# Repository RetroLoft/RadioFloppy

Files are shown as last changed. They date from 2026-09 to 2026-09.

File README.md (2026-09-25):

# RadioFloppy

WiFi-floppy-emulator voor de Atari ST op basis van een ESP32-S3 (Otronic DevKitC-clone,
16 MB flash, 8 MB PSRAM). Framework: ESP-IDF v5.5.5 (C).

## Hardwaretests

`main/main.c` kiest welke test draait (roep de gewenste functie uit `main/tests.h` aan):

| Test | Bestand | Wat |
| ---- | --- | --- |
| `floppy_emu_run()` (actief) | `main/floppy_app.c`, `ext_flash.c`, `image_store.c`, `drive_emu.c`, `flux_stream.c`, `mfm_track.c`, `disk_image.c` | **Read-only** floppy-emulatie als drive B: (`EMU_SELECT_LINE`). De image komt uit de imagebibliotheek op de externe SPI-flash U2 (S25FL128L, blokgebaseerd, zie `docs/FLASH_LAYOUT.md`) of uit een tijdelijke PSRAM-upload. Alle 168 sporen worden bij het opstarten naar MFM gecodeerd in PSRAM (FlashFloppy-layout voor .ST: geen IAM, GAP4a 80, GAP2 22, GAP3 84). RMT+DMA speelt de fluxstroom op GPIO41 (0,8 us pulsen, 10 MHz), een tweede RMT-kanaal de INDEX-puls op GPIO1 (3 ms per 200 ms, synchroon gestart). WPROT actief zodra geselecteerd; schrijven is uitgeschakeld. |
| `led_test_run()` | `main/led_test.c` | Laat een RGB-LED op GPIO38 blauw en op GPIO48 rood knipperen (om de on-board LED te vinden; op dit board: GPIO48). |
| (oud) `legacy/input_monitor.c` | niet gebouwd | Selectiebewuste monitor met TRACK0 uit de vorige fase, ter referentie. |
| `loopback_test_run()` | `main/loopback_test.c` | Zoekt continu welke Shugart-uitgang (ULN2003A) via een jumper op J1 met welke ingang (SN74LVC245A) verbonden is. |
| `button_test_run()` | `main/button_test.c` | Knoppen: GPIO19 = links (SW_NEXT), GPIO8 = rechts (SW_PREV); piept 0,5 s bij opstarten. |

**Loopbacktest:** de Shugart-lijnen hebben op de PCB geen pull-ups. Plaats op de jumper een
pull-up van 4,7–10 kΩ naar +3V3 (bijv. J3 pin 3, displayconnector), anders komt de lijn na het
vrijgeven van de uitgang niet betrouwbaar HIGH en wordt er niets gemeld.

**Webinterface:** `http://<ip>/` — Current Floppy, uploaden en *My floppy images* (laden, volgorde, vervangen, verwijderen, opslag in %) vanuit de browser
(`web/index.html`, in de firmware ingebouwd); tandwiel rechtsboven = instellingen (hostnaam,
firmware). **Knoppen:** links = vorige disk, rechts = volgende; beide 3 s = hostnaam en IP op het
display; beide 10 s = WiFi-setupmodus.

**WiFi-setupmodus:** zonder ingesteld netwerk (of na 10 s beide knoppen) opent RadioFloppy een
eigen WiFi-netwerk met één setup-pagina (netwerk, beveiliging, wachtwoord). De diskemulatie is dan
uit; het display toont netwerknaam, sleutel en adres. Zie `docs/API.md` → *WiFi setup mode*.

**WiFi en HTTP API:** `docs/API.md` — images uploaden (tijdelijk naar PSRAM of in de imagebibliotheek, tot
1,5 MiB), images activeren, ordenen, vervangen en verwijderen via `/api/v1/`. Hostnaam en WiFi-netwerk staan op de
externe flash (instellingen, setupmodus); `idf.py menuconfig` → *RadioFloppy* geeft alleen de
standaardwaarden en het optionele API-token, en staat alleen in `sdkconfig` (git-ignored). Standaard is de
API open op het thuisnetwerk. Tests:
`tests/host/run.sh` (op de PC), `tests/api/api_test.py` en `tests/web/ui_test.py` (tegen het board).

**STEP-geluid en status-LED:** bij iedere verwerkte STEP-puls van drive B: geeft de buzzer een tik van 3 ms (`main/step_sound.h`); de on-board RGB-LED (GPIO48) brandt rood-oranje zolang MOTOR actief is (`main/status_led.h`).

**Buzzer:** hangt aan het +5V-net van de PCB, dat alleen via J2 (floppyvoeding / Atari) gevoed
wordt: de 5V-pin van de Otronic-clone is alleen een ingang. Bij voeding via USB alleen is de
buzzer dus stil.

**Veiligheid Shugart-uitgangen:** `bootloader_components/early_pins` zet de zes uitgangs-GPIO's
(ULN2003A-ingangen) al in de bootloader op LOW; `shugart_outputs_release()` doet dat opnieuw als
eerste stap in `app_main()`.

**Floppy images:** de firmware bevat geen images. De emulator laadt de image uit de
imagebibliotheek op de externe SPI-flash (`docs/FLASH_LAYOUT.md`); is die leeg, ontbreekt hij of is
hij onbruikbaar, dan zit er geen disk in drive B:. Een flash met het oude 20-slotformaat wordt
herkend maar niet gelezen: initialiseren met `POST /api/v1/storage/format` (of de knop op de
website). `images/RETROLOFT_TEST_720K.ST` is alleen een testbestand in de repository.
Commerciële images blijven lokaal (`.gitignore`).

Volledige pinmapping: `main/board_pins.h`.

## Welke USB-poort?

Gebruik **uitsluitend de USB-poort van de USB-naar-UART-brug** (op het board meestal
gemarkeerd als `COM` of `UART`). De andere poort (`USB`) is de native USB van de ESP32-S3 en
zit direct op GPIO19/GPIO20. Die poort mag **niet** worden aangesloten: de host trekt D-/D+
via 15 kΩ naar GND, waardoor de rechterknop (GPIO19) permanent "ingedrukt" leest.

Controle onder Linux na het insteken:

```sh
lsusb
ls -l /dev/ttyUSB* /dev/ttyACM*
```

| `lsusb` toont | Poort |
| --- | --- |
| `10c4:ea60` Silicon Labs CP210x | UART-brug → goed (`/dev/ttyUSB0`) |
| `1a86:55d3` / `1a86:7523` QinHeng CH343/CH340 | UART-brug → goed (`/dev/ttyACM0` of `/dev/ttyUSB0`) |
| `303a:1001` Espressif USB JTAG/serial | native USB → **verkeerde poort** |

## Compileren, flashen en monitor

```sh
. ~/esp/esp-idf/export.sh           # eenmalig per terminal
cd FloppyEmulator-ESP32S3
idf.py set-target esp32s3           # alleen de eerste keer
idf.py build
idf.py -p /dev/ttyUSB0 flash monitor
```

Vervang `/dev/ttyUSB0` door de poort die hierboven is gevonden. Stoppen van de monitor:
`Ctrl+]`.

Verwachte uitvoer:

```
Floppy Emulator - Button Test
Ready. Press a button.
Left Button
Right Button
```

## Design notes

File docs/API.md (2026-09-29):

# RadioFloppy HTTP API — version 1

RadioFloppy is a WiFi floppy drive emulator for the Atari ST. It replaces a
real floppy drive (here: external drive **B:**) and plays `.ST` disk images
to the Atari. This API lets you put disk images on the device and choose
which one the Atari sees — from a script, a web page or any HTTP client.

- [Web interface](#web-interface)
- [Quick start](#quick-start)
- [Concepts](#concepts)
- [Authentication](#authentication)
- [Endpoint reference](#endpoint-reference)
- [Uploading images](#uploading-images)
- [Errors](#errors)
- [Client examples](#client-examples)
- [Limits and behaviour](#limits-and-behaviour)
- [Device configuration](#device-configuration)
- [WiFi setup mode](#wifi-setup-mode)

## Web interface

Open `http://<device>/` in a browser (PC or phone). The page is served by
the device itself, uses only this API and needs no internet access:

- **Current Floppy** — the disk the Atari sees now, its origin (my floppy
  images or temporary PSRAM image) and a warning when that image was
  replaced or deleted since.
- **Add a floppy** — upload a `.ST` file: temporarily (PSRAM), or add it to
  my floppy images (loaded at once unless unticked).
- **New disk** — a name and *Create*: an empty, formatted 720 KiB Atari
  disk in my floppy images, read-write (only when the computer is set to
  Atari 16-bit).
- **My floppy images** — all stored images in their order (`sequence`),
  each with **↑ ↓** (change the order), **Load**, **Replace…** (asks before
  the old image is lost) and **Delete**; above the list the storage use,
  e.g. *Storage: 61% used*.
- **Admin access** — only shown when the device has a token; it is kept only in the open page.
- **Settings** (gear icon, top right, `/#settings`) — connected computer, host name, floppy drive (A:/B:), buzzer on/off, compression, WiFi status,
  firmware version and a *Check for updates* button (not functional yet).

The page polls `GET /current` every 3 s and `GET /images` every 15 s (and
after changes), one request at a time, and pauses while it uploads or loads.
Source: `web/index.html`, embedded in the firmware.

## Front panel buttons

**Left** = previous disk, **right** = next disk, wrapping around. The list
is: the PSRAM image (if there is one), then every valid image in
`sequence` order. A press gives a click on the buzzer; the switch takes
about 0.4 s (360 KB) to 0.9 s (880 KB) and follows the same rules as
`PUT /current`.

Both buttons held **3 s**: the display shows the host name and IP address
for 10 s. Held on to **10 s**: RadioFloppy restarts in
[WiFi setup mode](#wifi-setup-mode). In setup mode, both buttons held 3 s
leave it without changes.

## Quick start

```sh
DEV=192.168.178.62            # the device address (see "Device configuration")
# What is the device doing?
curl -s http://$DEV/api/v1/status

# Which images are stored, and how full is the storage?
curl -s http://$DEV/api/v1/images

# Put a game on the drive right now (temporary, not stored)
F="Crystal Castles.st"
URL=$(curl -s -H "Content-Type: application/json" \
      -d "{\"filename\":\"$F\",\"size\":$(stat -c %s "$F"),\"destination\":\"psram\"}" \
      http://$DEV/api/v1/uploads | sed -n 's/.*"upload_url":"\([^"]*\)".*/\1/p')
curl -s -X PUT -H "Content-Type: application/octet-stream" --data-binary @"$F" http://$DEV$URL
```

(With a token configured, add `-H "Authorization: Bearer $TOKEN"`.)

## Concepts

### Base URL and formats

All endpoints live under `http://<device>/api/v1/`. Requests and responses
use JSON (`Content-Type: application/json`), except the image data itself,
which is sent as raw bytes (`application/octet-stream`) — never base64.
Plain HTTP on port 80; the API is meant for a trusted local network.

`v1` is the API version. Fields may be *added* to responses within v1;
clients should ignore fields they do not know. Incompatible changes get a
new version path.

### The active disk

At any moment the drive holds at most one disk: the **active disk**. It is
what the Atari reads from drive B:. It can come from

- **my floppy images** — the images stored on RadioFloppy, or
- **PSRAM** — one temporary image that is lost when the device restarts.

`GET /api/v1/current` tells you which one it is. After a restart the device
inserts the library image that was active last (else the one named
*Crystal Castles*, else the first valid image in `sequence` order); a PSRAM
image is gone. A stored image is always
read completely into PSRAM and prepared before the Atari sees it.

### My floppy images

Stored images are managed as **images**, never as storage places:

| Field | Meaning |
| --- | --- |
| `id` | Fixed number of the image (1–65535). Does not change when the order changes or the image is replaced; not reused while the image exists. |
| `sequence` | Position in lists (1 = first). Changing it never moves image data. |
| `status` | `valid`, or `incomplete`: replacing it failed or was interrupted — it holds no data; replace or delete it. |

The flash is divided into equal blocks (64 KiB on a 16 MiB chip, larger on
bigger chips; see `docs/FLASH_LAYOUT.md`); an image occupies as many blocks
as it needs, anywhere on the flash. Clients never see or choose blocks; the
storage use is reported as a percentage of all blocks (`used_percent`),
plus the exact numbers.

### Supported images

Raw `.ST` images (sector dumps without header) with

| Property | Supported |
| --- | --- |
| Cylinders | 79–84 (with 79, track 79 reads as unformatted) |
| Sectors per track | 9, 10 or 11 (512 bytes) |
| Sides | 1 or 2 |
| File size | up to 946 176 bytes (84/2/11); the storage limit is 1.5 MiB |

Examples: 360 KiB (80/1/9), 400 KiB (80/1/10), 410 KiB (82/1/10, e.g.
Nebulus), 440 KiB (80/1/11), 720 KiB (80/2/9), 800 KiB (80/2/10), 820 KiB
(82/2/10), 880 KiB (80/2/11).

The geometry follows from the file size alone (no supported size fits two
geometries). The boot sector (BPB) is only checked and reported in the
device log: many game disks have a custom or stale one, and some dumps are
shorter than their file system — the missing tracks then read as
unformatted, as they would from the real disk. Other geometries (8 sectors, 40 or 70
cylinders, HD with 18 sectors, …) are recognised but not supported
(`UNSUPPORTED_GEOMETRY`); anything above 1.5 MiB (1 572 864 bytes) is
refused as `IMAGE_TOO_LARGE`. `.MSA` is not supported. The Atari may
write to an image set to `READ_WRITE` (see *Writing*); otherwise the drive
reports the disk as write-protected.

HFE (HxC Floppy Emulator) files are uploaded with the `.hfe` extension,
only to the library (`"destination": "flash"`; the temporary PSRAM disk is
for `.ST` only). They are never whole in the device's memory: while the
file arrives it is checked, CRC-summed and compressed straight into free
storage blocks; afterwards the stored data is decompressed and checked
again (HFE format, length and CRC-32). Only then does the image appear;
an interrupted or refused upload leaves nothing behind. Checked are: HFEv1
and HFEv3 by their header; ISO MFM, 250 kbit/s, 1 or 2 sides, at most 84
cylinders, single step; the track table before the track data and the
tracks in ascending order (as HxC tools write them; other layouts are
refused with `UNSUPPORTED_FORMAT`); and that the decoded tracks fit the
drive's track buffer (else `IMAGE_TOO_LARGE`), so every stored HFE image
can be inserted. A file that is wrong from the start (e.g. HFEv2,
"HXCPICFE" revision 1: convert it to HFEv1 or HFEv3) is refused as soon
as its header has arrived; the rest of the data is still received but
ignored. An HFE file may be up to 3 MiB; compressed it must fit in the
blocks of one image (1.5 MiB), else `IMAGE_TOO_LARGE`. HFE images are
always READ_ONLY.

HFE images are played in their own timing: every track at its own cell
times, with the index pulse on the real start of the revolution. HFEv3
timing changes (`BITRATE`) are played; files made from flux dumps, with
thousands of tiny speed changes per track, are smoothed into zones that
keep the exact duration of every revolution. Weak bits (`RAND`) are
stored but not yet played as random data.

The track layout follows FlashFloppy: GAP3 84 (9 sectors), 30 (10
sectors) or 3 with interleave 2 (11 sectors). An 11-sector track is
longer than a standard track and is played with slightly shorter bitcells
(1.945 µs instead of 2 µs), so a revolution still takes 200 ms.

### Disk changes

When the active disk changes, the drive behaves like a real drive whose
door is opened and closed: for 0.7 s it shows no disk. The Atari (TOS)
notices this and reads the new disk's directory the next time you open
drive B:.

A disk can be changed while the Atari uses drive B:, as with a real drive
(many games keep the drive selected all the time). The device first waits
up to 0.3 s for the Atari to finish its access. It never changes a disk the
Atari is writing to: see [DRIVE_BUSY](#drive_busy).

## Authentication

By default there is **no token**: everyone on the local network can use the
whole API and the web page. RadioFloppy is meant for a home network.

Changing calls must send the right `Content-Type` (`application/json`, or
`application/octet-stream` for image data); anything else gets
`415 UNSUPPORTED_MEDIA_TYPE`. Browsers can only send such requests from
another web site after a CORS check, which RadioFloppy never allows, so a
foreign web page cannot change disks through your browser.

On a shared network a token can be configured (menuconfig →
RadioFloppy → *Optional API token*). Then every changing call needs

```
Authorization: Bearer <token>
```

(`X-API-Token: <token>` is accepted as well), a missing or wrong token gives
`401 UNAUTHORIZED`, `GET /status` reports `"auth_required": true`, and the
web page asks for the token.

## Endpoint reference

| Method and path | Token | Purpose (token only if one is configured) |
| --- | ----- | --- |
| `GET /api/v1/status` | | Device, WiFi, storage and drive status |
| `GET /api/v1/images` | | All images in `sequence` order + storage use |
| `POST /api/v1/images` | (yes) | Create a new, empty, formatted disk |
| `GET /api/v1/images/{id}` | | One image |
| `GET /api/v1/images/{id}/data`  | | Download the image file (uncompressed) |
| `PUT /api/v1/images/{id}` | (yes) | Change the position (`sequence`) |
| `DELETE /api/v1/images/{id}` | (yes) | Delete an image |
| `GET /api/v1/storage` | | Storage use and geometry |
| `POST /api/v1/storage/format` | (yes) | Initialise the storage (erases all images)  |
| `GET /api/v1/current` | | The active disk |
| `PUT /api/v1/current` | (yes) | Make a stored image the active disk |
| `POST /api/v1/uploads` | (yes) | Start an upload (new, replacement or PSRAM) |
| `PUT /api/v1/uploads/{id}/data` | (yes) | Send the image bytes of an upload |
| `GET /api/v1/uploads/{id}` | | State of an upload |
| `GET /api/v1/settings` | | Device settings, WiFi and firmware |
| `PUT /api/v1/settings` | (yes) | Change settings (host name) |
| `POST /api/v1/system/restart` | (yes) | Restart the device |
| `GET /api/v1/system/update` | | Check for firmware updates (placeholder) |

---

### `GET /api/v1/status`

Overall state of the device.

```json
{
  "device": "RadioFloppy",
  "api": "v1",
  "firmware": "1.0.0",
  "hostname": "RadioFloppy",
  "wifi": { "connected": true, "ssid": "MyNetwork", "ip": "192.168.178.62", "rssi": -38 },
  "storage": { "state": "valid", "used_percent": 26, "...": "as GET /storage" },
  "machine": { "id": "ATARI", "name": "Atari 16-bit", "supported": true },
  "drive": { "select_line": "DS1", "armed": true, "selected": false, "motor": false, "cylinder": 0 },
  "current": { "inserted": true, "source": "flash", "image_id": 1, "image_changed_since": false,
               "name": "Crystal Castles", "size": 368640, "crc32": "42ce7eed", "sides": 1 },
  "psram_free": 3928064,
  "auth_required": false,
  "psram_image": { "name": "Retroloft test", "size": 737280, "crc32": "c413f8cc", "sides": 2 },
  "upload": { "upload_id": "25", "state": "done", "...": "..." }
}
```

| Field | Meaning |
| --- | --- |
| `wifi.rssi` | Signal strength in dBm |
| `storage` | Same object as [`GET /storage`](#get-apiv1storage) |
| `machine` | Machine profile in use; `supported: false` = floppy emulation off  |
| `drive.select_line` | Which drive-select line the emulator answers to (`DS1` = drive B:) |
| `drive.armed` | The emulator has seen the Atari powered on and answers to it |
| `drive.selected` | The Atari is using our drive right now |
| `drive.motor` | The floppy motor line is on |
| `drive.cylinder` | Current head position (0–83) |
| `current` | Same object as [`GET /current`](#get-apiv1current) |
| `psram_free` | Free PSRAM in bytes |
| `auth_required` | A token is configured: changing calls need it |
| `psram_image` | The kept PSRAM image, if any (selectable with the buttons) |
| `upload` | The latest upload, if any (same object as [`GET /uploads/{id}`](#get-apiv1uploadsid)) |

---

### `GET /api/v1/images`

All images in `sequence` order, and the storage use.

```json
{
  "images": [
    { "id": 6, "sequence": 1, "status": "valid", "name": "Weird Dreams", "format": "st",
      "size": 839680, "stored_size": 839680, "storage_format": "raw", "crc32": "342b844d",
      "blocks_used": 13, "access": "READ_ONLY", "write_supported": true, "active": true },
    { "id": 3, "sequence": 2, "status": "incomplete", "name": "Leisure Suit Larry", "active": false }
  ],
  "storage": { "state": "valid", "used_percent": 26, "...": "as GET /storage" }
}
```

| Field | Meaning |
| --- | --- |
| `id`, `sequence`, `status` | See [My floppy images](#my-floppy-images) |
| `name` | Title (from the file name when it was uploaded) |
| `size` | Image size in bytes (only `valid`) |
| `stored_size`, `storage_format` | Bytes as stored and how: `raw` (= `size`) or `deflate` (compressed) |
| `crc32` | CRC-32 of the image as 8 hex digits (same as `zlib.crc32`, `crc32` command) |
| `blocks_used` | Number of storage blocks it occupies |
| `access` | `READ_ONLY` (default for every upload) or `READ_WRITE` — see below  |
| `write_supported` | The image format may be set to `READ_WRITE` (only ST for now) |
| `active` | This image is the active disk (and has not been replaced since it was activated) |

`GET /api/v1/images/{id}` returns one such object (`404 IMAGE_NOT_FOUND`
if there is none).

---

### `POST /api/v1/images`

Create a new, empty, formatted disk in my floppy images. Token required.

```json
{ "name": "Save games" }
```

- `name`: 1–52 printable ASCII characters (spaces around it are removed),
  else `400 INVALID_NAME`. Becomes the title of the image.
- The disk follows the **configured** computer (`machine` in the
  settings). **Atari 16-bit** (the only one for now): always `.ST`,
  720 KiB = 737 280 bytes, 80 tracks × 2 sides × 9 sectors × 512 bytes,
  formatted as TOS does it (boot sector with BPB, not executable, random
  serial number; two empty FATs; empty root directory for 112 entries;
  711 free clusters of 1 KiB). Other computers: `409 MACHINE_NOT_SUPPORTED`,
  nothing is created.
- A new disk is **`READ_WRITE`** (uploads are `READ_ONLY`); writing itself
  is not supported yet, see `PUT /images/{id}`.
- It is stored like an upload (12 blocks of 64 KiB, verified) and appears
  at the end of the list.

Response `201`: the image object. Other errors: `409 UPLOAD_BUSY`,
`503 STORAGE_NOT_READY`, `507 NO_SPACE`, `507 INSUFFICIENT_MEMORY`.

### `PUT /api/v1/images/{id}`

Change the order and/or the write setting. Token required. No image data
is read or written.

```json
{ "sequence": 1, "access": "READ_WRITE" }
```

- `sequence`: move the image to this position (1 = first; larger than the
  number of images = last); all images are renumbered 1…n.
- `access`: `"READ_ONLY"` or `"READ_WRITE"`. Stored in the catalog, kept
  after a restart. Only formats that can be written (ST for now; checked
  on the recognised format, not the file name) accept `READ_WRITE`, else
  `422 FORMAT_NOT_WRITABLE`. Uploads — also replacements — are always
  `READ_ONLY`; disks created on the device (planned) will start as
  `READ_WRITE`.

**Writing:** a `READ_WRITE` .ST image is presented writable (WPROT
released) when all of this holds: the computer is set to Atari 16-bit,
the image comes from the library (not a temporary PSRAM image), its
sectors could be kept in memory, the storage is usable, at least as many
blocks are free as the image has (so every save fits), and no save failed.
Otherwise the disk stays write-protected; `GET /current` → `write.reason`
says why. See [Writing](#writing).

Response `200`: the image object. Errors: `400 INVALID_REQUEST` (neither
field, `sequence` < 1, or another `access` value), `404 IMAGE_NOT_FOUND`
(also for an incomplete image), `422 FORMAT_NOT_WRITABLE`,
`503 STORAGE_NOT_READY`.

---

### `GET /api/v1/images/{id}/data`

The image file itself, as uploaded or as the computer wrote it — always
uncompressed, also when it is stored compressed (the CRC-32 is checked
before sending). `Content-Type: application/octet-stream`,
`Content-Disposition: attachment` with the title as file name and the
format's extension (`.st`, `.hfe`).

| Error | When |
| --- | --- |
| `404 IMAGE_NOT_FOUND` | No valid image with this id |
| `409 UNSAVED_CHANGES` | The active disk has writes that are not saved yet; try again once they are (a few seconds after the drive motor stops) |
| `500 FLASH_ERROR` | Reading or checking the stored image failed |
| `507 INSUFFICIENT_MEMORY` | No PSRAM for the image |

---

### `DELETE /api/v1/images/{id}`

Delete an image. Token required. Its blocks are free at once (erased only
when they are reused). If it is the active disk, the drive keeps playing it
until another disk is activated.

Response `200`:

```json
{ "id": 2, "status": "deleted", "storage": { "...": "as GET /storage" } }
```

| Error | When |
| --- | --- |
| `404 IMAGE_NOT_FOUND` | No image with this id |
| `409 UPLOAD_BUSY` | An upload replacing this image is in progress |
| `503 STORAGE_NOT_READY` | The storage is not usable |

---

### `GET /api/v1/storage`

```json
{ "state": "valid", "flash_detected": true, "jedec_id": "016018", "capacity": 16777216,
  "block_size": 65536, "blocks_total": 255, "blocks_used": 67, "blocks_free": 188,
  "used_percent": 26, "images": 6, "max_image_size": 1572864, "free_bytes": 12320768 }
```

| Field | Meaning |
| --- | --- |
| `state` | `valid`; `old_format` (an earlier RadioFloppy format — initialise it); `invalid` (unknown data or a different flash size — not touched); `no_flash` |
| `capacity` | Detected flash size in bytes |
| `block_size` | Storage block size (64 KiB for 16 MiB, 128 KiB for 32 MiB, …)  |
| `blocks_total`, `blocks_used`, `blocks_free` | Data blocks (at most 255) |
| `used_percent` | `blocks_used / blocks_total`, rounded |
| `images` | Number of valid images |
| `free_bytes` | `blocks_free × block_size` |

### `POST /api/v1/storage/format`

Initialise the storage: **every stored image is lost**. Needed once when the
flash still holds an older RadioFloppy format (`state: "old_format"`); a
completely erased flash is initialised automatically. Token required.

```json
{ "confirm": "ERASE ALL IMAGES" }
```

Response `200`: the storage object. Without the exact confirmation:
`400 CONFIRMATION_REQUIRED`. The disk in the drive stays loaded until
another disk is activated or the device restarts.

---

### `GET /api/v1/current`

The active disk.

```json
{ "inserted": true, "source": "flash", "image_id": 2, "image_changed_since": false,
  "name": "Nebulus", "size": 419840, "crc32": "40881c6a", "sides": 1,
  "cylinders": 82, "sectors": 10 }
```

| Field | Meaning |
| --- | --- |
| `inserted` | `false`: no disk in the drive (then only `source: "none"`) |
| `source` | `flash` (my floppy images), `psram` or `none` |
| `image_id` | Only for `flash`: the image it was loaded from |
| `image_changed_since` | Only for `flash`: that image was replaced or deleted since; the drive still plays the disk as it was when activated |
| `name`, `size`, `crc32` | The disk image |
| `sides`, `cylinders`, `sectors` | Geometry: 1 or 2 sides, 79–84 cylinders, 9–11 sectors per track |
| `write` | Write state of the inserted disk, see [Writing](#writing) |

---

### `PUT /api/v1/current`

Make a stored image the active disk. Token required.

```json
{ "image_id": 5 }
```

Response `200`: the new [`current`](#get-apiv1current) object. Takes about
0.4–0.9 s (the image is read through its blocks, its CRC checked, the
tracks prepared).

| Error | When |
| --- | --- |
| `400 INVALID_REQUEST`  | `image_id` missing or not a number 1–65535 |
| `404 IMAGE_NOT_FOUND`  | No valid image with this id |
| `409 DRIVE_BUSY` | The Atari kept writing to drive B:; nothing changed |
| `500 FLASH_ERROR` | The stored image could not be read or its CRC is wrong |

---

### `POST /api/v1/uploads`

Start an upload. Token required. See [Uploading images](#uploading-images).

Request fields:

| Field | Type | Required | Meaning |
| --- | --- | --- | --- |
| `filename` | string  | yes | Original file name; becomes the title (TOSEC tags removed, max. 52 characters). Only used as a name. |
| `size` | number  | yes | Exact size of the file in bytes |
| `destination` | string  | yes | `"psram"` (temporary) or `"flash"` (my floppy images) |
| `replace` | number  | no | Only with `"flash"`: id of the image to **replace** (keeps its id and position). Leave out to add a new image at the end. |
| `activate` | boolean | no | `"flash"`: make it the active disk afterwards (default `false`). `"psram"`: always activated; `false` is refused. |
| `crc32` | string  | no | CRC-32 of the file as hex, e.g. `"42ce7eed"`. If given, the received data must match. |

Response `201 Created`: an [upload object](#get-apiv1uploadsid) in state
`ready`, with the `upload_url` to send the data to:

```json
{ "upload_id": "26", "state": "ready", "name": "Crystal Castles", "size": 368640,
  "received": 0, "destination": "flash", "activate": false,
  "upload_url": "/api/v1/uploads/26/data" }
```

The size, geometry, image to replace and free space are checked here
already, so a client learns about most problems before sending any data.
When replacing, the blocks of the old image count as free.

| Error | When |
| --- | --- |
| `400 INVALID_REQUEST` | Missing/wrong fields, `psram` with `activate: false`, `replace` with `psram` |
| `404 IMAGE_NOT_FOUND` | `replace` names no image |
| `409 UPLOAD_BUSY` | Another upload is still in progress |
| `413 IMAGE_TOO_LARGE` | `size` above 1 572 864 bytes (1.5 MiB) |
| `422 INVALID_IMAGE` | `size` cannot be a floppy image |
| `422 UNSUPPORTED_GEOMETRY` | `size` is a `.ST` geometry that is not supported |
| `503 STORAGE_NOT_READY` | `flash`, but the storage is not usable |
| `507 NO_SPACE` | Not enough free blocks |
| `507 INSUFFICIENT_MEMORY` | Not enough memory for the upload |

---

### `PUT /api/v1/uploads/{id}/data`

Send the image bytes. Token required. Body: the complete file, nothing
else; `Content-Type: application/octet-stream`; `Content-Length` must equal
the announced `size`. Data can be sent only once per upload.

The request returns when everything is finished — received, checked, stored
and/or activated — typically 3–7 seconds. The response is the final
[upload object](#get-apiv1uploadsid):

```json
{ "upload_id": "26", "state": "done", "name": "Crystal Castles", "size": 368640,
  "received": 368640, "destination": "flash", "activate": false,
  "crc32": "42ce7eed", "image_id": 7, "active": false }
```

On failure the HTTP status matches the error, and the upload object has
`"state": "failed"` and an `error`:

```json
{ "upload_id": "27", "state": "failed", "name": "Crystal Castles", "size": 368640,
  "received": 100000, "destination": "flash", "activate": false,
  "error": { "code": "UPLOAD_INCOMPLETE", "message": "received 100000 of 368640 bytes" } }
```

| Error | When |
| --- | --- |
| `400 UPLOAD_INCOMPLETE` | `Content-Length` ≠ `size`, or the connection dropped |
| `404 UPLOAD_NOT_FOUND` | Unknown or superseded upload id |
| `409 UPLOAD_STATE` | Data was already sent for this upload |
| `409 DRIVE_BUSY` | Stored (if `flash`) but not activated — see below |
| `422 INVALID_IMAGE` / `UNSUPPORTED_GEOMETRY` | The content is not a supported `.ST` image |
| `422 CHECKSUM_MISMATCH` | Data does not match the given `crc32` |
| `422 UNSUPPORTED_FORMAT` | A recognised but unplayable format (e.g. HFEv2) |
| `500 FLASH_ERROR` | Writing or verifying failed (nothing stored; when replacing, the old image is lost) |
| `500 PREPARE_FAILED` | The disk could not be prepared for the drive |
| `507 NO_SPACE` | Not enough free blocks any more |
| `507 INSUFFICIENT_MEMORY`  | Not enough memory |

---

### `GET /api/v1/uploads/{id}`

State of an upload. Only the most recent upload is kept; older ids give
`404 UPLOAD_NOT_FOUND`.

| Field | Present | Meaning |
| --- | --- | --- |
| `upload_id` | always | Id (a string) |
| `state` | always | `ready`, `receiving`, `processing`, `done`, `failed` |
| `name` | always | Title derived from `filename` |
| `size`, `received` | always | Announced and received byte count |
| `destination` | always | `psram` or `flash` |
| `replace` | when replacing | The image being replaced |
| `activate` | always | Whether it will be / was activated |
| `upload_url` | state `ready` | Where to `PUT` the data |
| `crc32` | state `done` | CRC-32 of the received image |
| `image_id` | stored | The stored image (also on `DRIVE_BUSY`) |
| `active` | state `done` | It is now the active disk |
| `error` | state `failed` | `{ "code": ..., "message": ... }` |

### `GET /api/v1/settings`

```json
{
  "hostname": "RadioFloppy",
  "drive_select": "DS1",
  "drive_select_active": "DS1",
  "buzzer": true,
  "compression": false,
  "last_image_id": 6,
  "machine": "ATARI",
  "machine_active": "ATARI",
  "machine_supported": true,
  "machines": [ { "id": "ATARI", "name": "Atari 16-bit", "supported": true },
                { "id": "AMIGA", "name": "Commodore Amiga", "supported": false },
                { "id": "DOS", "name": "IBM PC / DOS", "supported": false } ],
  "restart_required": false,
  "wifi": { "ssid": "MyNetwork", "security": "wpa2", "connected": true,
            "ip": "192.168.178.62", "rssi": -38, "mac": "DC:DA:0C:12:34:56" },
  "firmware": { "version": "1.0.0", "idf": "v5.5.5" }
}
```

The WiFi password is never returned. `restart_required` is `true` when a
saved setting only takes effect after a restart (e.g. a new host name).

### `PUT /api/v1/settings`

Body (`Content-Type: application/json`), every field optional:

```json
{ "hostname": "Atari-B", "drive_select": "DS1", "buzzer": false, "machine": "ATARI" }
```

- `hostname`: 1–32 letters, digits or `-`, not starting or ending with `-`
  (else `422 INVALID_HOSTNAME`). Used for DHCP and for the name of the
  setup network. Takes effect after a restart.
- `drive_select`: `"DS1"` = drive **B:** (default, external second drive)
  or `"DS0"` = drive **A:** (only when the internal drive is disconnected);
  else `422 INVALID_DRIVE_SELECT`. Like the drive-select jumper of a real
  drive. Takes effect after a restart; `drive_select_active` in the answer
  is the line in use until then.
- `buzzer`: `true`/`false` — clicks for head steps and button presses.
  Takes effect at once.
- `compression`: `true`/`false` (default `false`) — images added from now
  on (uploads, new disks) are always stored compressed (raw deflate), and
  a writable disk is stored compressed each time its written sectors are
  saved. Checked before storing: the compressed data is inflated and must
  give the image's CRC, else it is stored uncompressed. Stored images are
  not converted. Typical results: 18–45% for game disks with free space,
  70–85% for full ones, a few KiB for a new empty disk; activating takes
  about the same time (0.5–1 s). A compressed writable disk is saved as a
  whole (compress, write all its blocks, one catalog update): a save takes
  a few seconds instead of about one.
- `machine`: the connected computer, `"ATARI"` (Atari 16-bit, default),
  `"AMIGA"` (Commodore Amiga) or `"DOS"` (IBM PC / DOS); else
  `422 INVALID_MACHINE`. Takes effect after a restart; `machine_active` is
  the profile in use until then. **Only `ATARI` is supported for now.** With
  another profile RadioFloppy starts without floppy emulation: no drive
  interrupts, no flux stream, all floppy outputs released; the web page,
  the API, the image library and WiFi setup keep working, activating a disk
  gives `409 MACHINE_NOT_SUPPORTED`, and `GET /status` reports
  `"machine": {"supported": false}`. Choose `ATARI` again and restart to
  get the drive back.

`last_image_id` (read only) is the library image that is loaded at the next
start-up. It is stored 5 s after the last disk change (so stepping through
disks with the buttons writes the flash once) and only when it changed; a
temporary PSRAM image is not remembered. If that image no longer exists,
the start-up falls back to *Crystal Castles*, else the first image.

Answer: the settings as with `GET`. The WiFi network is changed in
[WiFi setup mode](#wifi-setup-mode), not here.

### `POST /api/v1/system/restart`

Body `{}`. Answers `202 {"restarting": true}` and restarts about 1 s
later. The Atari loses drive B: for a few seconds; a PSRAM image is gone.

### `GET /api/v1/system/update`

Placeholder for online updates; always answers:

```json
{ "current": "1.0.0", "status": "not_available", "update_available": false,
  "message": "Online update checks are not available yet." }
```

## Writing

The Atari can write to a library `.ST` image set to `READ_WRITE` (for
example a disk made with *New disk*). What happens:

1. **Receive** — WDATA is sampled by an RMT receive channel with DMA
   (0.1 µs); a write ends when WDATA stays quiet for 16 µs.
2. **Decode** — MFM: three A1 syncs, data mark, 512 bytes, CRC. Only a
   complete sector with a correct CRC is used; anything else is ignored
   and counted in `writes_rejected` (the image is not touched). Formatting
   a track from the Atari is not supported.
3. **Which sector** — the WD1772 writes only the data field. RadioFloppy
   takes the rotation position when WGATE is asserted (time since the
   INDEX pulse) and the cylinder and side of that moment: the sector whose
   ID field just passed.
4. **Apply** — the sector is patched into the image kept in PSRAM and its
   track is encoded again, so the next read returns the new data.
5. **Save** — when the drive motor has been off for 2 s (one save per disk
   operation; at the latest a minute after the last write) the changed 64 KiB blocks are
   written **copy-on-write** to free blocks, read back, the whole image is
   checked against its new CRC, and **one** catalog update switches all of
   them. After a power cut the image on the flash is the previously saved
   or the newly saved version, never a mix of both.

`GET /api/v1/current` → `write`:

```json
{ "state": "pending", "writable": true, "reason": "", "unsaved": true,
  "sectors_written": 14, "writes_rejected": 0, "saves": 3 }
```

| `state` | Meaning |
| --- | --- |
| `read_only` | Write-protected; `reason` says why (read-only image, not enough free storage, …) |
| `writable`  | Writes accepted, everything saved |
| `pending` | Written sectors not saved yet (saved when the motor has been off for 2 s)  |
| `saving` | Being saved |
| `error` | Saving failed (`error`): the disk is write-protected, the changes stay in memory and are retried every 30 s (e.g. after storage was freed) |

Guarantees and limits:

- Changes are **not** lost by activating another disk, a restart through
  the API or the buttons (WiFi setup): those save first; if saving fails,
  they are refused with `409 UNSAVED_CHANGES`. Deleting, replacing or
  formatting while the disk has unsaved changes is refused the same way.
- A **power cut** loses the changes not saved yet: those of the disk
  operation in progress, plus 2 seconds and the time the save takes
  (about 1–4 s). What was saved
  before stays intact. Wait until the page shows *Writable — all changes
  saved* before switching off. Keeping the last seconds safe as well would
  need a hold-up supply (a capacitor that keeps RadioFloppy running for
  a few seconds) and power-fail detection — not on this hardware.
- If a file operation is interrupted by a power cut, the disk is left as a
  real floppy would be after a cut in the middle of writing: the saved
  version is consistent at block level, but the file system may lack the
  last sectors TOS wrote.

## Uploading images

An upload always takes two requests:

1. `POST /api/v1/uploads` with the options → `upload_url`
2. `PUT <upload_url>` with the file bytes → final result

```
ready ──PUT data──> receiving ──> processing ──> done
  │                     │              │
  │ (60 s, no data)     │ (dropped)    │ (invalid, flash error, drive busy)
  └──> failed <─────────┴──────────────┘
```

### Three kinds of upload

| You want to… | Request body |
| --- | --- |
| Play an image now, without storing it | `{"filename": "Game.st", "size": 368640, "destination": "psram"}` |
| Add an image to my floppy images | `{"filename": "Game.st", "size": 368640, "destination": "flash"}` |
| Replace image 5 and play the new version | `{"filename": "Game.st", "size": 368640, "destination": "flash", "replace": 5, "activate": true}` |

Add `"activate": true` to the second form to also play a stored image at
once.

### Guarantees

- The data is first received completely into memory. An image that is
  incomplete, invalid or does not match its `crc32` never touches the
  storage and never becomes the active disk.
- A new image only goes into free blocks, is read back and checked, and
  only then appears in the list. An interrupted store (also a power cut)
  leaves no image behind, and its blocks are free again.
- Without `replace`, a stored image is **never** overwritten.
- With `replace`, the old image is given up first, so replacing also works
  when the storage is nearly full (its blocks are reused first). **If the
  upload then fails, or the power fails while writing, the old image is
  lost** — the image shows `incomplete`, never a half image.
- A PSRAM upload replaces the previous PSRAM image only once the new one is
  complete and prepared. There is only one PSRAM image.

### DRIVE_BUSY

A new active disk is switched in right away while the Atari is not using
drive B:, and after 0.3 s also while it is (reading only). A disk the Atari
writes to is never changed under it: once the Atari has written to a
writable disk since it selected drive B:, the disk only changes after the
Atari releases the drive. The device waits up to 3 seconds for that. If
the Atari keeps the drive busy longer, the request ends with
`409 DRIVE_BUSY` and the old disk stays in the drive:

- `flash` upload: the image *is* stored (`image_id`) — activate it later
  with `PUT /api/v1/current`.
- `psram` upload: nothing is kept — upload it again later.

## Errors

Every error response has the same shape:

```json
{ "error": { "code": "NO_SPACE", "message": "not enough free storage: 14 blocks needed, 9 free" } }
```

`code` is stable and meant for programs; `message` is for people and may
change. A failed upload carries the same `error` inside its upload object.

| HTTP | Code | What to do |
| ---- | --- | --- |
| 400  | `INVALID_REQUEST` | Fix the request |
| 400  | `CONFIRMATION_REQUIRED` | Send the exact confirmation text |
| 400  | `UPLOAD_INCOMPLETE` | Start a new upload and send the complete file |
| 401  | `UNAUTHORIZED` | Send the correct token (only when one is configured) |
| 415  | `UNSUPPORTED_MEDIA_TYPE` | Send `Content-Type: application/json` / `application/octet-stream` |
| 404  | `IMAGE_NOT_FOUND` | Use an id from `GET /images` |
| 404  | `UPLOAD_NOT_FOUND` | Start a new upload |
| 409  | `UPLOAD_BUSY` | Wait for the running upload (or its 60 s timeout) |
| 409  | `UPLOAD_STATE` | Start a new upload |
| 409  | `DRIVE_BUSY` | Retry when the Atari is idle (see above) |
| 413  | `IMAGE_TOO_LARGE` | Only images up to 1 572 864 bytes (1.5 MiB) |
| 422  | `INVALID_IMAGE` | The file is not a floppy image |
| 422  | `UNSUPPORTED_GEOMETRY` | Use an image with 79–84 tracks and 9–11 sectors |
| 422  | `CHECKSUM_MISMATCH` | The file was damaged in transit — send it again |
| 422  | `UNSUPPORTED_FORMAT` | A recognised format that cannot be played (yet), e.g. HFEv2 |
| 422  | `INVALID_HOSTNAME` | Use 1–32 letters, digits or `-` |
| 422  | `INVALID_DRIVE_SELECT` | Use `"DS0"` or `"DS1"` |
| 400  | `INVALID_NAME` | Use 1–52 printable characters |
| 422  | `FORMAT_NOT_WRITABLE`  | Only ST images can be set to `READ_WRITE` |
| 422  | `INVALID_MACHINE` | Use `"ATARI"`, `"AMIGA"` or `"DOS"` |
| 409  | `UNSAVED_CHANGES` | The Atari wrote to the disk and it is not saved yet — wait and retry |
| 409  | `MACHINE_NOT_SUPPORTED` | Floppy emulation is off for this computer — choose `ATARI` and restart |
| 500  | `FLASH_ERROR` | Storage problem — retry; check the device log |
| 500  | `PREPARE_FAILED` | Internal problem — check the device log |
| 503  | `STORAGE_NOT_READY` | Storage not usable (see `GET /storage`, maybe initialise it) |
| 507  | `NO_SPACE` | Delete an image, or replace one |
| 507  | `INSUFFICIENT_MEMORY`  | Retry later / after a restart |

## Client examples

### Shell (curl)

```sh
DEV=192.168.178.62
TOKEN=your-api-token

# upload FILE DESTINATION [extra JSON, e.g. ',"replace":5,"activate":true']
upload() {
    size=$(stat -c %s "$1")
    url=$(curl -s -H "Authorization: Bearer $TOKEN" -H "Content-Type: application/json" \
          -d "{\"filename\":\"$(basename "$1")\",\"size\":$size,\"destination\":\"$2\"$3}" \
          http://$DEV/api/v1/uploads | sed -n 's/.*"upload_url":"\([^"]*\)".*/\1/p')
    [ -n "$url" ] || { echo "upload refused"; return 1; }
    curl -s -X PUT -H "Authorization: Bearer $TOKEN" \
         -H "Content-Type: application/octet-stream" \
         --data-binary @"$1" http://$DEV$url; echo
}

upload "Crystal Castles.st" psram                          # play now, not stored
upload "Crystal Castles.st" flash                          # add to my floppy images
upload "Crystal Castles.st" flash ',"replace":5,"activate":true'   # replace image 5, play it

# Play image 1 / move image 3 to the top / delete image 5
curl -s -X PUT -H "Authorization: Bearer $TOKEN" -H "Content-Type: application/json" \
     -d '{"image_id":1}' http://$DEV/api/v1/current
curl -s -X PUT -H "Authorization: Bearer $TOKEN" -H "Content-Type: application/json" \
     -d '{"sequence":1}' http://$DEV/api/v1/images/3
curl -s -X DELETE -H "Authorization: Bearer $TOKEN" http://$DEV/api/v1/images/5
```

(To see the full answer of the first step, run it without the `sed` part.)

### Python (standard library only)

```python
import http.client, json, os, zlib

DEV, TOKEN = "192.168.178.62", "your-api-token"

def call(method, path, body=None, data=None):
    conn = http.client.HTTPConnection(DEV, 80, timeout=60)
    headers = {"Authorization": "Bearer " + TOKEN}
    if body is not None:
        data, headers["Content-Type"] = json.dumps(body).encode(), "application/json"
    elif data is not None:
        headers["Content-Type"] = "application/octet-stream"
    conn.request(method, path, body=data, headers=headers)
    resp = conn.getresponse()
    result = json.loads(resp.read() or b"{}")
    conn.close()
    return resp.status, result

def upload(path, destination="flash", **options):
    data = open(path, "rb").read()
    request = {"filename": os.path.basename(path), "size": len(data),
               "destination": destination, "crc32": "%08x" % zlib.crc32(data), **options}
    status, up = call("POST", "/api/v1/uploads", request)
    if status != 201:
        raise RuntimeError(up["error"])
    status, up = call("PUT", up["upload_url"], data=data)
    if up.get("state") != "done":
        raise RuntimeError(up.get("error", up))
    return up

print(upload("Crystal Castles.st", "flash", activate=True))
print(call("GET", "/api/v1/images")[1])
```

A complete test suite that exercises every endpoint and error is in
`tests/api/api_test.py`.

## Limits and behaviour

| Item | Value |
| --- | --- |
| Image size / geometry | 79–84 cyl, 9–11 sectors, 1–2 sides (up to 946 176 bytes); storage limit 1.5 MiB |
| Stored images | as many as fit: 255 blocks (64 KiB each on 16 MiB), at least 1 block per image |
| PSRAM images | 1 |
| Uploads at the same time | 1 |
| Upload without data expires | after 60 s |
| Network timeout while sending | 10 s without data → `UPLOAD_INCOMPLETE` |
| Wait for drive to be idle | 0.3 s, then changed anyway unless the Atari writes to it; up to 3 s → else `DRIVE_BUSY` |
| Disk change signal to the Atari | 0.7 s "no disk" |
| Typical duration | Activate an image: 360 KB ≈ 0.4 s, 880 KB ≈ 0.9 s; store 880 KB ≈ 7 s; PSRAM upload 720 KB ≈ 3 s |
| Disk name | title from `filename` (TOSEC tags removed, `(Disk n/m)` kept), max. 52 characters |

- The device handles one request at a time; a long upload delays other
  requests until it is done.
- The emulated drive keeps working while the API is used. Uploading or
  deleting never disturbs the disk the Atari is reading.
- Restarting the device removes the PSRAM image and inserts the library
  image that was active last (see `last_image_id`), else the image named
  *Crystal Castles*, else the first valid image in `sequence` order.

## Device configuration

The host name and the WiFi network are stored on the external flash
(`docs/FLASH_LAYOUT.md`, settings sectors). They are set with the web page:
the host name under **Settings**, the WiFi network in
[WiFi setup mode](#wifi-setup-mode).

Until settings are saved there, the values from the firmware configuration
are used (`idf.py menuconfig` → *RadioFloppy*: WiFi SSID, WiFi password,
Hostname). These are stored only in the local `sdkconfig` file, which is
not part of the repository. The optional API token is only set there:

```sh
idf.py menuconfig        # → RadioFloppy: defaults, API token
idf.py build flash
```

- No WiFi network set at all: RadioFloppy starts in WiFi setup mode.
- No token (default): the API is open on the local network.
- Its address: hold both buttons 3 s (display), or see the serial console:
  `WiFi: connected to "…", IP 192.168.178.62, API http://192.168.178.62/api/v1/status`.

If you set a token, choose a long random one, e.g. `python3 -c "import secrets; print(secrets.token_hex(16))"`.

## WiFi setup mode

For first use and for moving to another network. RadioFloppy opens its own
WiFi network with a single setup page; **the floppy emulation is off**.

It starts:

- automatically when no WiFi network is set;
- when both buttons are held for 10 s (the display shows
  *WiFi setup mode / Restarting...*);
- automatically when new WiFi settings did not work (see below).

The display shows what to do:

```
WiFi setup mode
RadioFloppy-3A4F        <- network name (host name + end of the MAC address)
Key k7mqx2pa            <- WPA2 key, new random key every time
http://192.168.4.1/
```

Join that network with a phone or computer. Most devices open the setup
page by themselves ("sign in to network"); otherwise open
`http://192.168.4.1/`. The page lists the networks nearby (strongest
first, with signal and lock); pick one or type the name of a hidden
network, choose the security and enter the password (*Show password*
shows it while typing). *Save and connect* stores the settings and
restarts RadioFloppy, which then joins the network.

If it cannot join within 45 s, it returns to setup mode and the page says
why: network not found, wrong password, security type, or no address.
Setup mode is left without changes with *Leave setup without changes* or
both buttons for 3 s (only when a network was set before). A reset or
power cycle also returns to normal mode.

Security options (the lowest security accepted):

| Value  | Page text |
| --- | --- |
| `wpa2` | WPA2/WPA3 Personal (recommended) |
| `wpa3` | WPA3 Personal only |
| `wpa`  | WPA/WPA2 Personal (older routers) |
| `open` | Open network (no password) |

Setup API (only in setup mode, on the device's own network):

| Method and path | Purpose |
| --- | --- |
| `GET /api/v1/setup` | Reason for setup mode, current network (no password), last join error |
| `GET /api/v1/setup/scan` | `{"networks": [{"ssid", "rssi", "security", "supported"}]}` |
| `PUT /api/v1/setup/wifi` | `{"ssid", "security", "password"}` — save and restart. An empty password for the same network keeps the saved one |
| `POST /api/v1/setup/exit` | `{}` — restart without changes (`409 NOT_CONFIGURED` if no network is set) |

Every other URL redirects to the setup page; a small DNS server answers
every name with the device's address.

## Implementation notes

For firmware developers; clients do not need this.

- Code: `main/api.c` (endpoints, uploads), `main/st_image.c` (image
  checks), `main/disk_image.c` (active disk, two PSRAM track buffers),
  `main/image_store.c` (image library: blocks, catalog, the image reader;
  see `docs/FLASH_LAYOUT.md`),
  `main/wifi_net.c`, `main/settings.c` (settings on the external flash),
  `main/setup_mode.c` (setup access point, DNS, setup page `web/setup.html`).
- WiFi, lwIP and the HTTP server run on core 1; the floppy interrupts and
  the flux stream on core 0. WiFi keeps its credentials in RAM and starts
  before the flux stream, so no internal-flash write stalls the caches while
  the drive runs.
- New disks are encoded into the inactive of two PSRAM track buffers,
  switched under the drive lock, never while the computer writes to a
  writable disk (the switch inverts WPROT and gates INDEX/RDATA for 0.7 s,
  so a selected drive sees an opened and closed door), and then verified
  again in the background (`DISK_BACKGROUND_VERIFY`).
- API, buttons and web page change disks through one module,
  `main/disk_switch.c`, serialised by one mutex.

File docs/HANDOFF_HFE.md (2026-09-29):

# Handoff: HFE support (state at 2026-09-28)

For whoever continues this work (a new Claude session or a person). Read
this first; it replaces the chat history of the previous session.

## Where things stand

| Branch | Commit | State |
| --- | --- | --- |
| `main` | latest | **`wip/hfe-player` merged (2026-09-29).** Phase 2 (the HFE player) with `HFE_PLAYBACK 1`: ST regression passes, HFEv1 and HFEv3 games load on the Atari. Timing not yet measured. |
| `wip/hfe-player` | same as `main` | Kept for reference; new work starts from `main`. |

The board runs firmware built from `main`. Work on board revision 1 is
paused; the next steps below still apply, next to the preparation for
board revision 2 (DS0/DS1 pull-ups; being manufactured).

## First device test of phase 2 (2026-09-28)

- ST regression on the new firmware: `api_test.py` 68 ok / 0 FAIL,
  `ui_test.py` 49 ok / 0 FAIL. Stored images unchanged.
- Start-up with an HFE disk inserted works: `HFE tracks: HFEv1, 80
  cylinders, 2 side(s), 250 kbit/s, 1958 KiB of track buffer, 2106 ms`.
- HFE uploads with `activate: true` take ~12 s for 2 MB (stored ~390 KB
  deflated). An upload while the Atari reads the drive gives
  `409 DRIVE_BUSY` (stored, not inserted), as designed.
- Test files: 75 HFEv1 files converted from STX (`..._stx.hfe`, the "P"
  set of the TOSEC Atari ST collection), in the user's OneDrive folder
  `retro/P` next to this repo.

| Image (id on the board) | Disk layout | Result on the Atari |
| --- | --- | --- |
| Pang [cr Bad Brew Crew] (185) | own loader, no BPB (boot sector filled with E5) | **works** |
| Pink Panther (187) | normal, 10 sectors, side 0 only, 82 cylinders | **works** |
| P-47 (184) | copy-protected: tracks 2–38 have no standard sectors (1–2 syncs + one long block, 100192–100208 cells); root directory is random bytes | boots to the intro screen, **hangs** after it |
| Pac-land (186) | normal GEMDOS, 11 sectors, side 0 only | **works** (file names correct in GEM) |
| Pang, later in the game | track 36 of this file lacks sector 2 (only 720 bytes of room where a 1024-byte sector belongs): the image is damaged | hangs at track 36, as any emulator would |
| **Klax (HFEv3)** (217) | flux dump (Greaseweazle SCP → HxC HFEv3), see below | **works** |

P-47 is the test case for the measurement tool: the image itself looks
complete (valid MFM on all tracks), so either the STX→HFEv1 conversion
lost something (e.g. weak bits) or the player's timing / track-change
position is off on these long custom tracks.

### HFEv3 from flux dumps (Klax)

Source: the Internet Archive item `Klax_Domark_AtariST_DiskImage`; the
7z holds SCP dumps, two STX conversions,
an HxC HFEv3 and an Aufit protection report. Local copy in OneDrive
`retro/HFEv3`. Protection report: tracks 0–4 have fuzzy sectors 11/12,
sector-within-sector, data over the index and no-flux areas.

What the HFEv3 contains, and how it is handled now (`main/hfe.c`):
- 2200–3600 `BITRATE` opcodes per track, values 70–75 around 72: the
  speed jitter of the dumping drive. A track with more changes than
  `HFE_MAX_SEGMENTS` (now 32) is **smoothed**: equal zones, each at the
  average cell time of its cells, the division remainder carried to the
  next zone, so the revolution keeps its duration (< 0.1 us off).
- `INDEX` repeated 16–24 cells before the track end (same pulse at the
  end of the revolution): ignored in the last 1/64 of the track; a repeat
  elsewhere is still refused.
- Tracks 80–82 are unformatted noise (thousands of `RAND`): weak areas
  beyond the limit are joined.
- The fuzzy sectors are **not** encoded as `RAND` in this file, so it
  does not test weak bits. A weak-bit test file must still be made (e.g.
  from the Aufit STX in the same archive, with HxC).
- Needs 2067 KiB of track buffer (2132 KiB available); stored 657 KB.
- Decision for later (SD card board): keep smoothing; stream tracks per
  cylinder from the card and raise `HFE_MAX_SEGMENTS` instead of playing
  every jitter step.

### Other changes in this round

- **Disk change while the drive is selected** (`drive_swap_media`): after
  0.3 s a disk is also changed while the Atari keeps drive B: selected
  (many games do; with the Atari off the select line floats low on board
  revision 1, which lacks the DS0/DS1 pull-ups). Refused only for a
  writable disk while WGATE is active or after a write since the drive
  was selected; then `DRIVE_BUSY` after 3 s. The 0.7 s disk change signal
  keeps INDEX/RDATA off, so no half sector of the new disk is read.
  Needs testing on the Atari (game holding the drive, Atari off,
  multi-disk game).
- Web UI: success messages disappear after 15 s; an upload refused by the
  device stops the progress bar; "Load temporarily" is disabled for HFE.

Cosmetic issues seen:
- Titles keep the converter suffix: "P-47 _stx" (TOSEC tags are removed,
  `_stx` and the space before it are not).
- The boot log prints the ST lines (`Geometry: 80/2/0/512`, `MFM: ...
  100000 bitcells/track, GAP3 84`, `RPM: 300 (200 ms, INDEX 3 ms)`) also
  for an HFE disk; `/current` reports `"sectors": 0` and no format.
- `flux_hfe_stats` (`late_pulses`) is not printed or exposed anywhere yet.

## HFE plan (phases, approved by the user)

1. **Parser / validator + streaming upload**: done (on `main`).
2. **Native timing player**: on `wip/hfe-player`; HFEv1 and HFEv3 games
   load on the Atari. Timing not yet measured.
3. **HFEv3 opcodes in the player**: weak bits (RAND) still to do (stored in
   the packed track, not yet played). Timing segments (BITRATE) work,
   including smoothed flux dumps.

After every phase: host tests plus the ST regression on the device
(`tests/api/api_test.py`, `tests/web/ui_test.py`). Then the user tests on
the Atari: HFEv1 first, then HFEv3, then copy-protected images.

## User requirements (keep these)

- The **ST route must stay completely unchanged**, including write support.
  The ST data encoder (`flux_encode`) and the 200 ms INDEX hardware loop
  are untouched; HFE uses separate encoders.
- **INDEX must sit on the real revolution boundary** of the flux stream and
  must never drift through an independent timer.
- Measure timing on real hardware; don't assume.
- HFE is always READ_ONLY and always stored compressed. HFEv2 is refused
  with a clear message; v1/v3 are detected from the header.
- Never accept an image that cannot be activated (track buffer fit is
  checked with the same packing code the player uses).
- An image becomes VALID in the catalog only after the complete upload,
  decompression, format check and CRC check.
- No STX/IPF/SCP now (STX research is parked). An SD card connector is
  planned for a later board; large images will go there.
- HFE test files: `/mnt/retroloft/retro/FLOPPIES/HFE` (1442 files, all
  HFEv1). 1436 pass, 6 are too large for the track buffer, none have an
  unsupported layout. No real HFEv3 files exist yet; the plan is to build
  HxC `hxcfe` and convert STX to HFEv3.

## How the pieces fit

- `main/hfe.c`: streaming reader (header, track table, one cylinder at a
  time in a 64 KiB region). It decodes into a **packed track buffer**: a
  slot table (`hfe_slot_t`, 168 slots) followed per track by cells (MSB
  first, 32-bit aligned), timing segments and weak areas. Checking a file
  runs the same packing in count-only mode.
- `main/hfe_import.c`: upload → CRC + early check + streaming deflate into
  reserved flash blocks (`image_store_writer_*`) → afterwards inflate from
  flash and check again → commit.
- `main/img_codec.c`: streaming deflate (worker task on core 1, ROM tdefl)
  and streaming inflate.
- **Phase 2 (this branch):**
  - `main/flux_stream.c`: `FLUX_MODE_HFE`, set with `flux_stream_set_mode`,
    which restarts both RMT channels in sync on an ST↔HFE disk change.
  - `hfe_encode`: plays the packed track at its own cell times and records
    the RMT tick of every revolution boundary in a ring buffer.
  - `hfe_index_encode`: puts the 3 ms pulse exactly on those ticks. While
    the next boundary isn't known yet it emits 10 µs filler steps, so it
    never runs further ahead than the data encoder. Late pulses are
    counted (`flux_hfe_stats`).
  - On a track change, the position in the new track follows from the time
    elapsed since the last boundary.
  - `main/disk_image.c`: `disk_prepare_hfe` / `build_hfe` inflate from flash
    straight into the inactive track buffer. `disk_tracks_kind` tells the
    encoders what the buffer holds. Start-up with an HFE disk is supported.
  - `main/disk_switch.c`: HFE images go through `disk_prepare_hfe`.
  - `main/api.c`: after an HFE upload, `activate` inserts the disk.

## Next steps

1. ~~Flash `wip/hfe-player` with `HFE_PLAYBACK 1`, ST regression, upload
   and insert an HFE file.~~ Done 2026-09-28, see above.
2. **Measurement tool (not built yet)**, with P-47 as the failing case: capture INDEX and RDATA on the
   device itself and verify:
   - the INDEX period equals the track duration;
   - the first flux pulse after INDEX is at the same offset every revolution
     (no drift);
   - `late_pulses` stays 0;
   - the stream keeps running during an HFE upload (user requirement 3:
     compression and flash writes must not disturb emulation; PSRAM
     bandwidth contention is the risk).

   Idea: MCPWM capture on the INDEX pad, and on the INDEX edge briefly
   capture the first RDATA edges. Or loop RDATA back into the MFM decoder
   and count sector CRC errors.
3. Show the format (ST/HFE) in the API status / current and in the web UI.
4. Phase 3: weak bits (RAND) in `hfe_encode` (random cells per revolution
   inside the weak areas).
5. Only when this works: `HFE_PLAYBACK 1` on `main`, update the docs, then
   the user tests on the Atari.

## Known loose ends

- `tests/web/ui_test.py` is sometimes flaky: the drag-handle arrow step
  and the replace check each failed once and passed on the rerun.
- A power cut during an HFE upload was only tested on the host, not on the
  device.

## Working with this user and project

- Communication in Dutch; code, web UI and docs in English.
- Work phase by phase. After a finished step, report and **ask before
  starting the next phase**. "proceed" after a commit question means:
  commit only.
- Commit/push only when asked. "commit" has meant "commit and push".
  End commit messages with the Co-Authored-By line.
- Never do a full chip erase without permission. Never commit WiFi
  credentials or tokens (they live only in the git-ignored `sdkconfig`).
  Never pass client-provided paths to file functions. Never silently wipe
  or move images.
- Device: ESP32-S3 N16R8, API at `http://192.168.178.62` (DHCP, may
  change). Serial `/dev/ttyACM0`; opening the port resets the board.
  ESP-IDF 5.5.5 (`. ~/esp/esp-idf/export.sh`; `idf.py -p /dev/ttyACM0
  build flash`).
- Tests:
  - host: `tests/host/run.sh` (extra real HFE files via `HFE_TEST_FILES`;
    on the Windows laptop run it from Git Bash with
    `PATH=/c/msys64/ucrt64/bin:$PATH`);
  - device: `RADIOFLOPPY_HOST=<ip> python3 tests/api/api_test.py` and
    `tests/web/ui_test.py` (needs websocket-client and Chrome; set
    `CHROME` to the Chrome executable where it isn't `google-chrome`).
  - `api_test.py` needs `images/CRYSTAL_CASTLES.ST` (git-ignored); it can be
    downloaded from the board (`GET /api/v1/images/1/data`, CRC 42ce7eed).
  - The tests leave the first original image active, not the one that was
    active before.
- Second machine: Windows laptop, same network. ESP-IDF 5.5.5 in
  `C:\Users\frank\esp\esp-idf` (`. C:\Users\frank\esp\esp-idf\export.ps1`),
  build dir outside OneDrive: `idf.py -B C:\Users\frank\esp\build-radiofloppy
  -p COM3 build flash`. Serial port COM3 (CH343). Its `sdkconfig` has no WiFi
  credentials; the board uses the ones saved on its external flash. Turn
  off the WireGuard `retroloft` tunnel there: it also routes
  192.168.178.0/24 and hides the board.

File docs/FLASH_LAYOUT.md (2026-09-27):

# RadioFloppy external flash layout — block-based image library

Floppy images live on the external SPI NOR flash U2, separate from the
ESP32-S3 firmware flash. No file system: the flash is divided into logical
blocks; block 0 holds the catalog and the settings, all other blocks hold
image data. An image is an ordered list of blocks, which do not have to be
contiguous. All constants are in `main/flash_layout.h`, the code in
`main/image_store.c` (host tests: `tests/host/test_image_store.c`).

Fitted chip: Infineon/Cypress **S25FL128L** (JEDEC `01 60 18`), 16 MiB,
4 KiB erase sectors, 64 KiB erase blocks, 256-byte pages, erased = `0xFF`.
Driven by the ESP-IDF generic chip driver in single SPI mode
(`main/ext_flash.c`). Nothing depends on this chip or on 16 MiB: the
capacity is detected at run time (`esp_flash_get_size`, from the JEDEC ID).

## Block geometry

Block numbers are stored as `uint8_t`, so there are at most **256 logical
blocks**: block 0 (metadata) plus at most **255 data blocks** (1…255). The
block size is the smallest power of two of at least 64 KiB for which the
capacity needs at most 256 blocks:

| Flash capacity | Block size | Data blocks | Blocks for 1.5 MiB |
| ---: | ---: | ---: | ---: |
| 8 MiB | 64 KiB | 127 | 24 |
| 16 MiB | 64 KiB | 255 | 24 |
| 32 MiB | 128 KiB | 255 | 12 |
| 64 MiB | 256 KiB | 255 | 6 |
| 128 MiB | 512 KiB | 255 | 3 |

Block *n* starts at `n × block_size`. A logical block is not an erase unit:
it is erased in 4 KiB sectors / 64 KiB erase blocks as needed, and only as
far as an image actually uses it.

The fitted 16 MiB chip: **64 KiB blocks, 255 data blocks** (blocks 1–255 =
`0x010000`–`0xFFFFFF`).

## Block 0

Whatever the block size, only the first 64 KiB of block 0 are used:

| Start | End | Size | Use |
| --- | --- | --- | --- |
| `0x000000` | `0x005FFF` | 24 KiB | Catalog copy A |
| `0x006000` | `0x00BFFF` | 24 KiB | Catalog copy B |
| `0x00C000` | `0x00CFFF` | 4 KiB  | Settings copy A |
| `0x00D000` | `0x00DFFF` | 4 KiB  | Settings copy B |
| `0x00E000` | `0x00FFFF` | 8 KiB  | Reserved |

## Catalog (one 24 KiB copy, little endian)

| Offset | Size | Content |
| --- | --- | --- |
| 0 | 64 | Header |
| 64 | 255 × 96 | Image records (at most one image per data block) |
| 24 544 | 28 | Unused (`0xFF`) |
| 24 572 | 4 | Commit word `0x21544D43` ("CMT!"), written **last** |

Header:

| Offset | Type | Field | Value |
| --- | ---- | --- | --- |
| 0 | u32  | magic | `0x4C494652` ("RFIL") |
| 4 | u16  | version | 3 (2 is still read and written as 3 at the next update; 1 was the 20-slot catalog "RFSL") |
| 6 | u16  | header_size | 64 |
| 8 | u32  | generation | +1 on every catalog write; highest valid wins |
| 12 | u32  | crc32 | CRC-32 over header + records, this field = 0  |
| 16 | u32  | capacity | Flash size the catalog was made for |
| 20 | u32  | block_size | Logical block size |
| 24 | u16  | data_blocks | Number of data blocks |
| 26 | u16  | record_size | 96 |
| 28 | u16  | record_count | 255 |
| 30 | u8 | max_blocks_per_image | 24 |
| 31 | u8 | reserved | 0 |
| 32 | u32  | max_image_size | 1 572 864 (1.5 MiB): the most one image occupies in the blocks |
| 36 | u16  | next_id | Id for the next new image |
| 38 | 26 | reserved | 0 |

Image record (96 bytes):

| Offset | Type | Field | Meaning |
| --- | --- | --- | --- |
| 0 | u16 | id | Image id 1–65535, fixed for the life of the image |
| 2 | u16 | sequence | Display order; changing it never moves data |
| 4 | u8 | status | `0xFF` unused record, `0x01` valid, `0x02` incomplete |
| 5 | u8 | format | bits 0–5: image format as recognised from the contents: `0x01` ST (the only one supported); `0x05` HFE (HFEv1) and `0x08` HFEv3, both always READ_ONLY (HFE playback is in development); reserved `0x02` MSA, `0x03` STX, `0x04` IPF, `0x06` ADF, `0x07` IMG. Bit 7: write setting, 1 = READ_WRITE, 0 = READ_ONLY (default; records from before this setting read as READ_ONLY). Bit 6: reserved, 0 |
| 6 | u8 | storage_format | `0x00` RAW (the image itself), `0x01` DEFLATE (raw deflate, RFC 1951; also for writable disks, which are then saved as a whole) |
| 7 | u8 | block_count | Blocks used (0 when incomplete) |
| 8 | u32 | original_size  | Image size in bytes (the logical size: for DEFLATE up to 3 MiB, see below) |
| 12 | u32 | stored_size | Bytes in the blocks (RAW: = original_size; DEFLATE: compressed size, ≤ `original_size + original_size/64 + 1024`) |
| 16 | u32 | crc32 | CRC-32 (IEEE, as zlib `crc32()`) of the image |
| 20 | u8[24] | blocks | Block numbers in image byte order (unused entries 0) |
| 44 | char[52]  | name | Title, NUL terminated when shorter than 52 characters |

Image byte *o* is in block `blocks[o / block_size]` at offset
`o % block_size`. `main/image_store.c` (`image_store_read`) is the only code
that turns image offsets into flash addresses; the MFM encoder gets the
whole image from PSRAM and knows nothing about blocks.

### Validation when loading

A catalog copy is used only if magic, version, sizes, CRC and commit word
are right, the geometry in the header equals the detected one, and every
record is consistent:

- status valid or incomplete (or unused); ids unique and not 0;
- valid: RAW with `1 ≤ original_size ≤ 1.5 MiB` and `stored_size ==
  original_size`, or DEFLATE with `1 ≤ original_size ≤ 3 MiB` (version 3;
  1.5 MiB in a version 2 catalog) and `1 ≤ stored_size ≤ original_size +
  original_size/64 + 1024` (the deflate worst case);
  `block_count` = the blocks `stored_size` needs, at most 24 and at most
  the blocks of 1.5 MiB at this block size;
- every block number in 1…`data_blocks`, and no block used twice (across
  all valid records);
- incomplete: `block_count` 0.

Otherwise the other copy is used; if neither is usable, nothing is written
(see *States* below).

### Updates

A catalog update never touches the copy in use: the new catalog
(generation + 1) is written to the other copy, read back and only then
given its commit word. A power cut during an update leaves the previous
generation in place.

**New image:** size ≤ 1.5 MiB → pick free blocks (lowest numbers first,
not necessarily contiguous; free = not in any valid record) → erase and
program only those blocks (the last one only as far as needed) → read the
image back through its block list and check the CRC-32 → catalog update
with the record *valid*. A power cut before that leaves no record; the
blocks count as free again.

**Delete:** catalog update without the record. The blocks are free at
once; they are erased only when reused.

**Replace** (keeps id and sequence): first check that the old blocks plus
the free blocks suffice (else nothing changes) → catalog update with the
old record *incomplete* and without blocks → use the old blocks first, then
free ones → erase, program, read back, CRC → catalog update with the record
*valid*. Replacing therefore works on a nearly full flash. If it fails, the
old image is lost, but the record stays *incomplete* and is never offered
as a disk.

**Order:** the image moves to a position and all sequences are renumbered
1…n (catalog update only).

**Compression** (setting *Compress new images*, off by default): a new
image is deflated (ROM miniz), inflated again and CRC-checked before
anything is stored; when that succeeds it is stored DEFLATE (also when it
did not get smaller: at most `size + size/64 + 1024` bytes), else RAW.
`crc32` is always that of the image itself; a load reads the stored
bytes, inflates them and checks the CRC. Images already stored are never
converted.

**Written compressed disks** (`image_store_commit_image`): written sectors
of a DEFLATE image (or of any image while compression is on) are saved by
storing the whole image anew — compressed, to free blocks, read back — and
one catalog update switching blocks, sizes, storage format and CRC.

**Sectors written by the computer** (`image_store_commit_blocks`, RAW
images with compression off): every
changed block of the image is written to a *free* block and read back;
then the whole image (unchanged blocks from the flash plus the new ones)
is checked against the new CRC-32, and one catalog update puts the new
block numbers and the CRC in the record. The old blocks become free. A
power cut before that update leaves the previous version intact. This is
why an image is only offered writable while at least as many blocks are
free as it has.

### States

| State | Condition | Action |
| --- | --- | --- |
| `valid` | A usable catalog copy | — |
| `blank` | Both catalog copies erased | Empty catalog written at once |
| `old_format` | 20-slot catalog ("RFSL" at `0x2000`/`0x3000`) or first catalog ("RFCT" at `0x0000`/`0x1000`) | Not read; `POST /api/v1/storage/format` |
| `invalid` | Unknown/damaged data, or a catalog for another flash size | Not touched; format on request only |

Formatting erases both catalog copies and writes an empty catalog
(generation 1) to copy A; image data is not erased (its blocks are free and
get erased when reused). There is no migration from the 20-slot format.

## Settings (one 4 KiB sector per copy, little endian)

Device settings (`main/settings.c`): same scheme as the catalog. A save
erases and writes the copy *not* in use (generation + 1), reads it back and
only then writes the commit word; the valid copy with the highest generation
wins. Until anything is saved, the firmware uses its menuconfig defaults.

| Offset | Type | Field | Meaning |
| --- | --- | --- | --- |
| 0 | u32 | magic | `0x54534652` ("RFST") |
| 4 | u16 | version | 5 (older versions are still read: 4 = without compress, that byte 0; 3 = 152 bytes without machine → Atari; 2 = also without buzzer_off/last_image_id, those bytes 0; 1 = 148 bytes, read as DS1) |
| 6 | u16 | size | record size in bytes (156) |
| 8 | u32 | generation | +1 on every save |
| 12 | u32 | crc32 | CRC-32 over the record with this field = 0 |
| 16 | char[33] | hostname | NUL terminated |
| 49 | char[33] | wifi_ssid | NUL terminated, empty = no network |
| 82 | char[65] | wifi_pass | NUL terminated (plain text) |
| 147 | u8 | wifi_security  | 0 WPA2/WPA3, 1 WPA3 only, 2 WPA/WPA2, 3 open |
| 148 | u8 | drive_select | 0 = DS0 (drive A:), 1 = DS1 (drive B:) |
| 149 | u8 | buzzer_off | 0 = buzzer on (default), 1 = off |
| 150 | u16 | last_image_id  | Image active at power-off (0 = none); written 5 s after the last disk change, only when it differs |
| 152 | u8 | machine | 0 = Atari 16-bit (default), 1 = Commodore Amiga, 2 = IBM PC / DOS (only 0 supported yet) |
| 153 | u8 | compress | 1 = store new read-only images compressed (default 0) |
| 154 | 2 | padding | 0 |
| 4092 | u32 | commit | `0x21544D43` ("CMT!"), written last |

The WiFi password is stored in plain text: anyone with the board in hand can
read the flash chip.

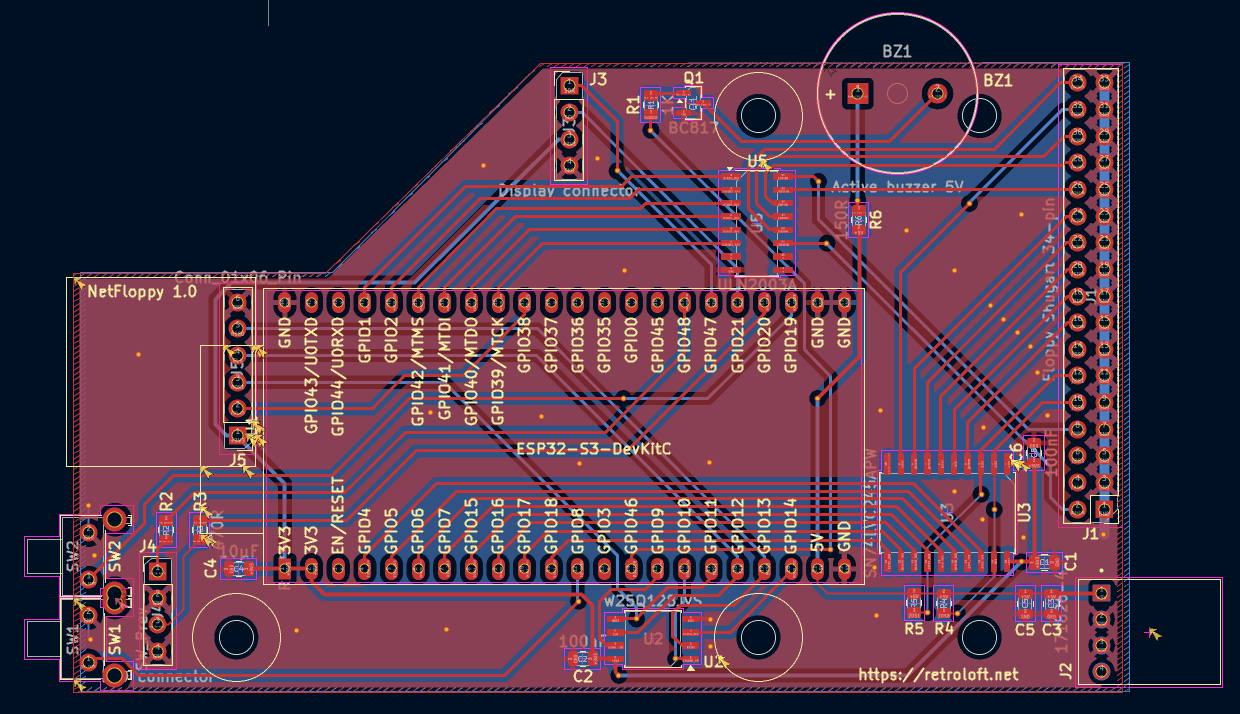
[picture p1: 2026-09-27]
hardware/v1.1/board.png

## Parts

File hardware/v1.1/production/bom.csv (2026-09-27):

Designator | Footprint | Quantity | Value | LCSC Part #
BZ1 | Buzzer_15x7.5RM7.6 | 1 | Active buzzer 5V
C1, C2, C3, C6 | 0805 | 4 | 100nF
C4 | 0805 | 1 | 10µF
C5 | 0805 | 1 | 47µF
J1 | PinHeader_2x17_P2.54mm_Vertical | 1 | Floppy Shugart 34-pin
J2 | TE_171826-4 | 1 | 171826-4
J3 | PinHeader_1x04_P2.54mm_Vertical | 1 | Display connector
J4 | PinHeader_1x04_P2.54mm_Vertical | 1 | LED connector
J5 | PinHeader_1x06_P2.54mm_Vertical | 1 | Conn_01x06_Pin
Q1 | SOT-23 | 1 | BC817
R1 | 0805 | 1 | 1K
R2, R3 | 0805 | 2 | 470R
R4, R5 | 0805 | 2 | 10K
R6 | 0805 | 1 | 150R
SW1 | SW_Tactile_SKHH_Angled | 1 | SW_Prev
SW2 | SW_Tactile_SKHH_Angled | 1 | SW_Next
U1 | ESP32-S3-DevKitC-OTRONIC | 1 | ESP32-S3-DevKitC
U2 | SOIC-8_5.3x5.3mm_P1.27mm | 1 | W25Q128JVS
U3 | SOIC-20W_7.5x12.8mm_P1.27mm | 1 | SN74LVC245APW
U5 | SOIC-16_3.9x9.9mm_P1.27mm | 1 | ULN2003A

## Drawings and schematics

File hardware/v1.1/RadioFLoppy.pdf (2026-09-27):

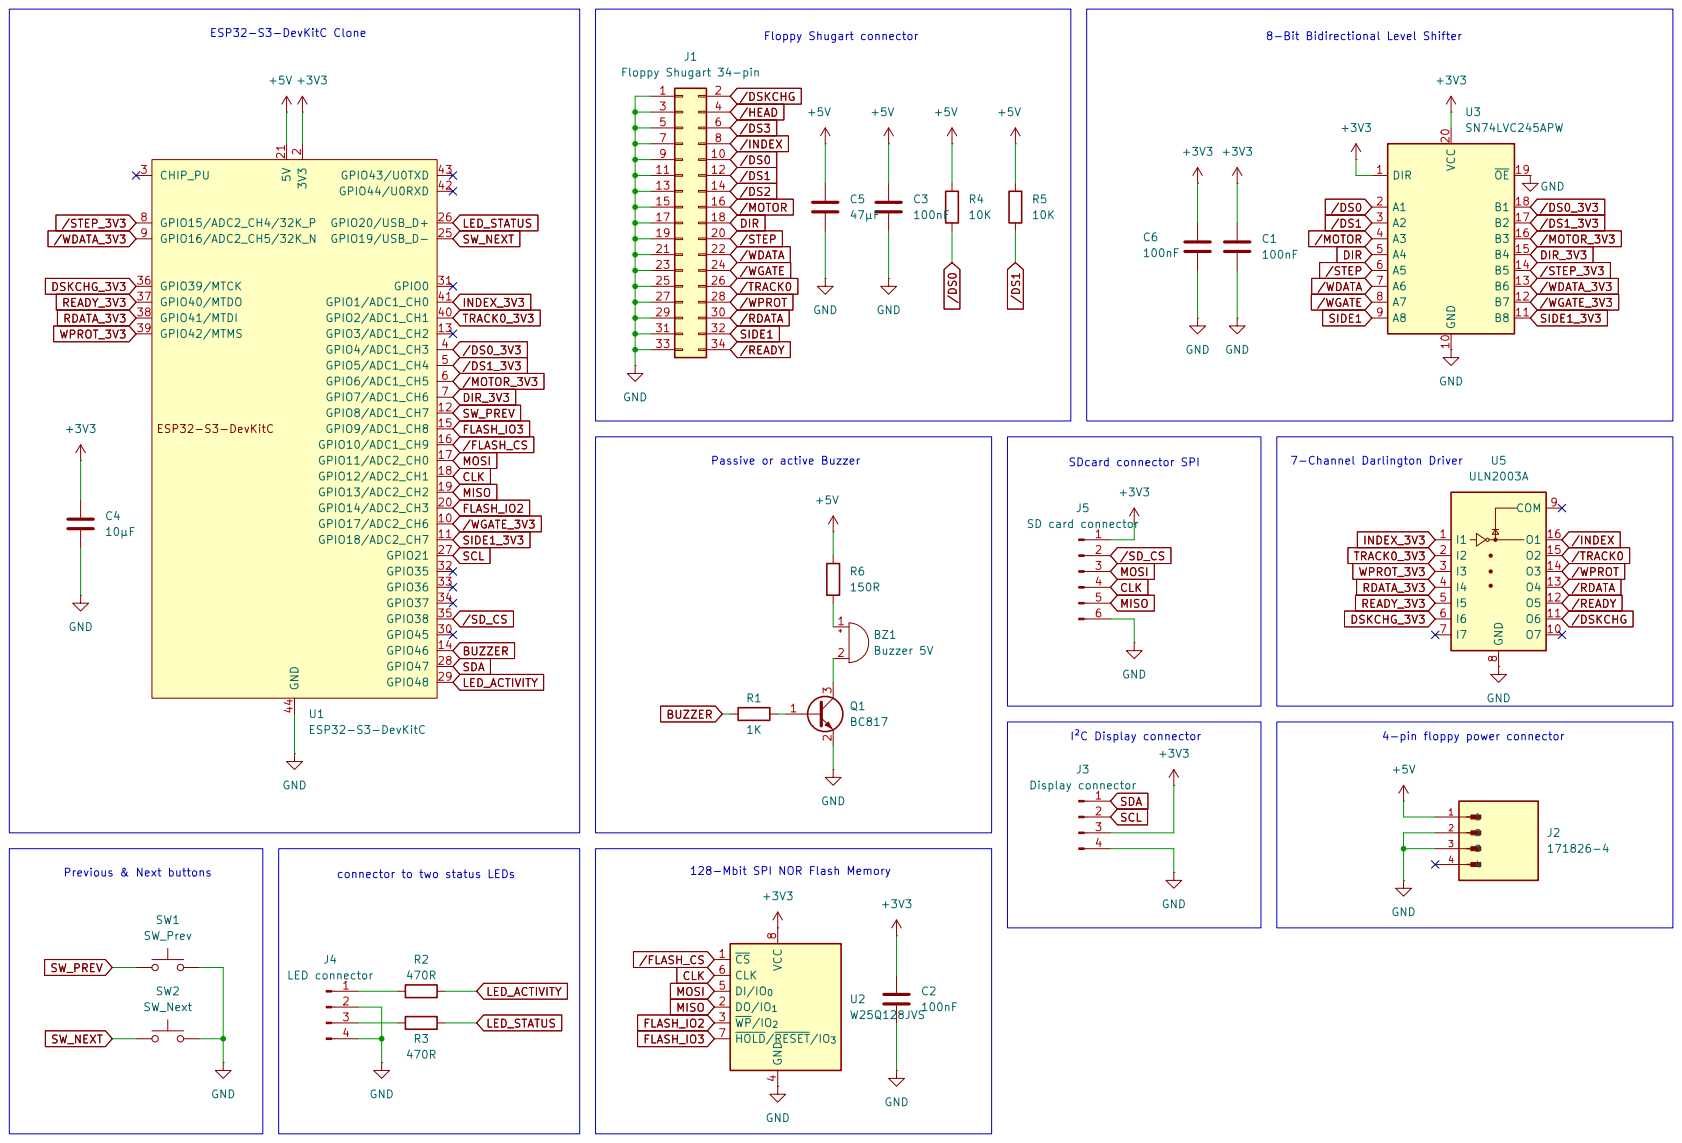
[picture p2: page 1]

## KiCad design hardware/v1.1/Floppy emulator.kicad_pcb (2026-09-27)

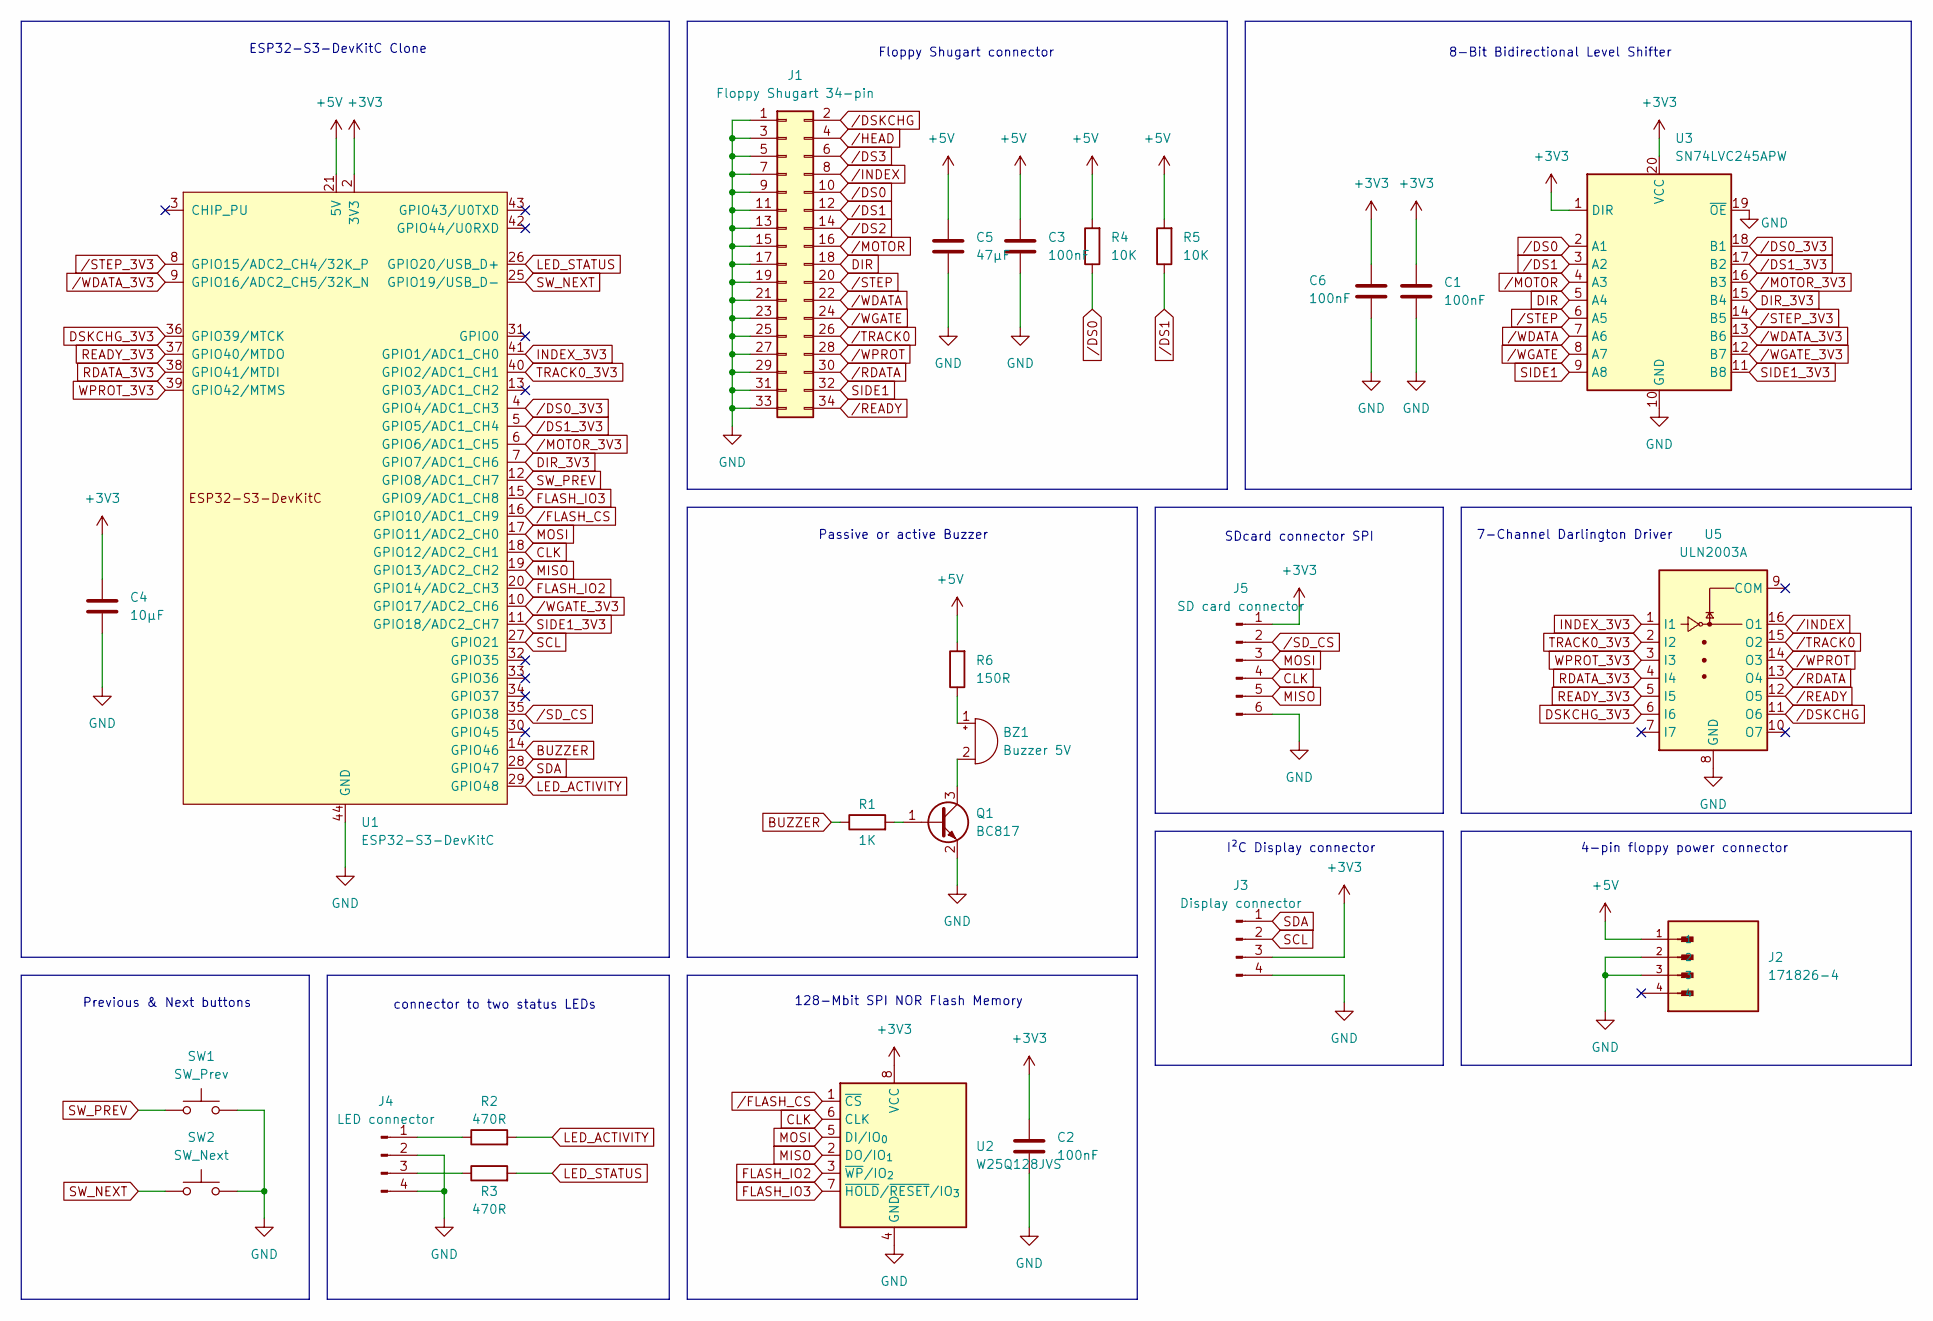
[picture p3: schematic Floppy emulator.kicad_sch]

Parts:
BZ1: Buzzer 5V; Buzzer_15x7.5RM7.6
C1, C2, C3, C6: 100nF; C_0805_2012Metric
C4: 10µF; C_0805_2012Metric
C5: 47µF; C_0805_2012Metric
J1: Floppy Shugart 34-pin; PinHeader_2x17_P2.54mm_Vertical
J2: 171826-4; TE_171826-4
J3: Display connector; PinHeader_1x04_P2.54mm_Vertical
J4: LED connector; PinHeader_1x04_P2.54mm_Vertical
J5: SD card connector; PinHeader_1x06_P2.54mm_Vertical
Q1: BC817; SOT-23
R1: 1K; R_0805_2012Metric
R2, R3: 470R; R_0805_2012Metric
R4, R5: 10K; R_0805_2012Metric
R6: 150R; R_0805_2012Metric
SW1: SW_Prev; SW_Tactile_SKHH_Angled
SW2: SW_Next; SW_Tactile_SKHH_Angled
U1: ESP32-S3-DevKitC; ESP32-S3-DevKitC-OTRONIC
U2: W25Q128JVS; SOIC-8_5.3x5.3mm_P1.27mm
U3: SN74LVC245APW; SOIC-20W_7.5x12.8mm_P1.27mm
U5: ULN2003A; SOIC-16_3.9x9.9mm_P1.27mm

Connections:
+3V3: C1.1, C2.1, C4.1, C6.1, J3.3, J5.1, U1.1 (3V3), U1.2 (3V3), U2.8 (VCC), U3.1 (DIR), U3.20 (VCC)
+5V: C3.1, C5.1, J2.1, R4.2, R5.2, R6.2, U1.21 (5V)
BUZZER: R1.1, U1.14 (GPIO46)
CLK: J5.4, U1.18 (GPIO12/ADC2_CH1), U2.6 (CLK)
DIR: J1.18, U3.5 (A4)
DIR_3V3: U1.7 (GPIO7/ADC1_CH6), U3.15 (B4)
DSKCHG_3V3: U1.36 (GPIO39/MTCK), U5.6 (I6)
FLASH_IO2: U1.20 (GPIO14/ADC2_CH3), U2.3 (~WP/IO_{2})
FLASH_IO3: U1.15 (GPIO9/ADC1_CH8), U2.7 (~HOLD/~RESET/IO_{3})
GND: C1.2, C2.2, C3.2, C4.2, C5.2, C6.2, J1.1, J1.3, J1.5, J1.7, J1.9, J1.11, J1.13, J1.15, J1.17, J1.19, J1.21, J1.23, J1.25, J1.27, J1.29, J1.31, J1.33, J2.2, J2.3, J3.4, J4.2, J4.4, J5.6, Q1.2 (E), SW1.2, SW2.2, U1.22 (GND), U1.23 (GND), U1.24 (GND), U1.44 (GND), U2.4 (GND), U3.10 (GND), U3.19 (~OE), U5.8 (GND)
INDEX_3V3: U1.41 (GPIO1/ADC1_CH0), U5.1 (I1)
LED_ACTIVITY: R2.2, U1.29 (GPIO48)
LED_STATUS: R3.2, U1.26 (GPIO20/USB_D+)
MISO: J5.5, U1.19 (GPIO13/ADC2_CH2), U2.2 (DO/IO_{1})
MOSI: J5.3, U1.17 (GPIO11/ADC2_CH0), U2.5 (DI/IO_{0})
unnamed: BZ1.1 (+), R6.1
unnamed: BZ1.2 (-), Q1.3 (C)
unnamed: J4.1, R2.1
unnamed: J4.3, R3.1
unnamed: Q1.1 (B), R1.2
RDATA_3V3: U1.38 (GPIO41/MTDI), U5.4 (I4)
READY_3V3: U1.37 (GPIO40/MTDO), U5.5 (I5)
SCL: J3.2, U1.27 (GPIO21)
SDA: J3.1, U1.28 (GPIO47)
SIDE1: J1.32, U3.9 (A8)
SIDE1_3V3: U1.11 (GPIO18/ADC2_CH7), U3.11 (B8)
SW_NEXT: SW2.1, U1.25 (GPIO19/USB_D-)
SW_PREV: SW1.1, U1.12 (GPIO8/ADC1_CH7)
TRACK0_3V3: U1.40 (GPIO2/ADC1_CH1), U5.2 (I2)
WPROT_3V3: U1.39 (GPIO42/MTMS), U5.3 (I3)
/DS0: J1.10, R4.1, U3.2 (A1)
/DS0_3V3: U1.4 (GPIO4/ADC1_CH3), U3.18 (B1)
/DS1: J1.12, R5.1, U3.3 (A2)
/DS1_3V3: U1.5 (GPIO5/ADC1_CH4), U3.17 (B2)
/DS2: J1.14
/DS3: J1.6
/DSKCHG: J1.2, U5.11 (O6)
/FLASH_CS: U1.16 (GPIO10/ADC1_CH9), U2.1 (~CS)
/HEAD: J1.4
/INDEX: J1.8, U5.16 (O1)
/MOTOR: J1.16, U3.4 (A3)
/MOTOR_3V3: U1.6 (GPIO6/ADC1_CH5), U3.16 (B3)
/RDATA: J1.30, U5.13 (O4)
/READY: J1.34, U5.12 (O5)
/SD_CS: J5.2, U1.35 (GPIO38)
/STEP: J1.20, U3.6 (A5)
/STEP_3V3: U1.8 (GPIO15/ADC2_CH4/32K_P), U3.14 (B5)
/TRACK0: J1.26, U5.15 (O2)
/WDATA: J1.22, U3.7 (A6)
/WDATA_3V3: U1.9 (GPIO16/ADC2_CH5/32K_N), U3.13 (B6)
/WGATE: J1.24, U3.8 (A7)
/WGATE_3V3: U1.10 (GPIO17/ADC2_CH6), U3.12 (B7)
/WPROT: J1.28, U5.14 (O3)

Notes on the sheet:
Previous & Next buttons
8-Bit Bidirectional Level Shifter
Passive or active Buzzer
connector to two status LEDs
SDcard connector SPI
I²C Display connector
Floppy Shugart connector
7-Channel Darlington Driver
4-pin floppy power connector
ESP32-S3-DevKitC Clone
128-Mbit SPI NOR Flash Memory

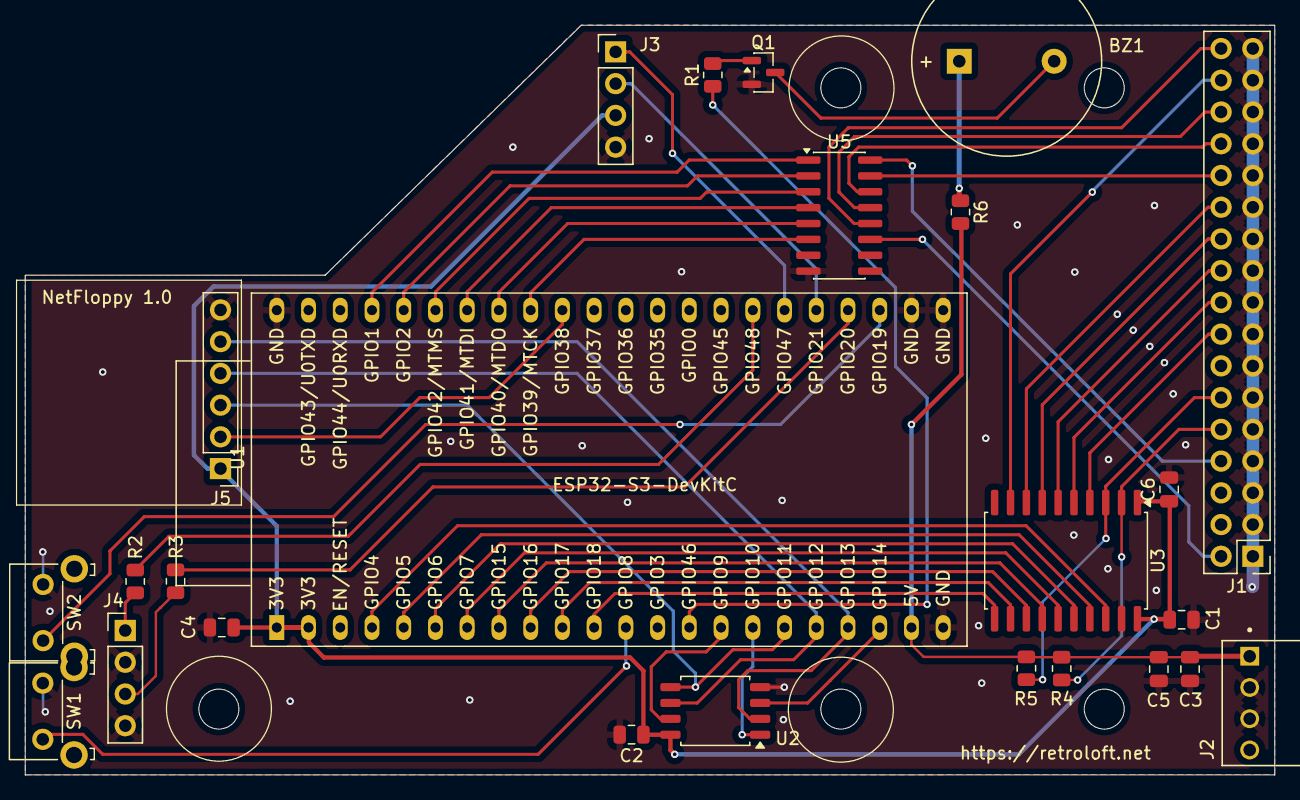
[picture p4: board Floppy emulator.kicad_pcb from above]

Board: 2 copper layers, 100.0 x 60.0 mm, 25 parts (0 on the bottom side), 50 nets.

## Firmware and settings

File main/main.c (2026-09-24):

/*
 * FloppyEmulator-ESP32S3 - hardware bring-up firmware.
 *
 * Runs one of the hardware tests from tests.h; change the call below to
 * select another test.
 */
#include "tests.h"

void app_main(void)
{
    /* First: keep every Shugart output released (a real Atari may be on). */
    shugart_outputs_release();
    usb_phy_release_pins();

    floppy_emu_run();
}

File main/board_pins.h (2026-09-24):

/*
 * Pin mapping of the FloppyEmulator-ESP32S3 PCB (prototype v1).
 *
 * Source: "Floppy emulator.kicad_pcb" (U1 footprint pads), verified against
 * the ESP32-S3-DevKitC-1 header pinout on 2026-09-23. All pins match.
 * Only the BTN_* pins are used in the current (button test) phase;
 * everything else is documented here for later phases and must NOT
 * be initialised yet.
 */
#pragma once

#include "driver/gpio.h"

/* Push buttons: switch to GND, use internal pull-up, active low.
 * Physically (verified on the board) SW_PREV is the RIGHT button and
 * SW_NEXT the LEFT one - the opposite of the original design notes. */
#define PIN_BTN_PREV        GPIO_NUM_8   /* SW1 / SW_PREV - right */
#define PIN_BTN_NEXT        GPIO_NUM_19  /* SW2 / SW_NEXT - left (also native USB D-) */

/* Console: UART0 via the DevKitC USB-to-UART bridge. */
#define PIN_UART0_TX        GPIO_NUM_43
#define PIN_UART0_RX        GPIO_NUM_44

/* ---- Later phases: not used yet --------------------------------------- */

/* Shugart inputs (Atari -> ESP32) through SN74LVC245A, active low. */
#define PIN_FDD_DS0         GPIO_NUM_4
#define PIN_FDD_DS1         GPIO_NUM_5
#define PIN_FDD_MOTOR       GPIO_NUM_6
#define PIN_FDD_DIR         GPIO_NUM_7
#define PIN_FDD_STEP        GPIO_NUM_15
#define PIN_FDD_WDATA       GPIO_NUM_16
#define PIN_FDD_WGATE       GPIO_NUM_17
#define PIN_FDD_SIDE        GPIO_NUM_18

/* Shugart outputs (ESP32 -> Atari) through ULN2003A (open collector):
 * GPIO HIGH = line pulled LOW on the connector = signal asserted. */
#define PIN_FDD_INDEX       GPIO_NUM_1
#define PIN_FDD_TRK0        GPIO_NUM_2
#define PIN_FDD_WPROT       GPIO_NUM_42
#define PIN_FDD_RDATA       GPIO_NUM_41
#define PIN_FDD_READY       GPIO_NUM_40
#define PIN_FDD_DSKCHG      GPIO_NUM_39

/* External SPI NOR flash (W25Q128JVS in schematic, verify fitted part). */
#define PIN_NOR_CS          GPIO_NUM_10
#define PIN_NOR_MOSI        GPIO_NUM_11   /* IO0 */
#define PIN_NOR_CLK         GPIO_NUM_12
#define PIN_NOR_MISO        GPIO_NUM_13   /* IO1 */
#define PIN_NOR_WP          GPIO_NUM_14   /* IO2 */
#define PIN_NOR_HOLD        GPIO_NUM_9    /* IO3 */

/* Optional I2C display. */
#define PIN_I2C_SDA         GPIO_NUM_47
#define PIN_I2C_SCL         GPIO_NUM_21

/* Active 5 V buzzer via BC817 (also native USB D+). */
#define PIN_BUZZER          GPIO_NUM_20

/* External status LEDs (not fitted yet). Note: the on-board RGB LED of
 * this DevKitC clone is on GPIO48 (v1.0 layout), shared with LED_STATUS. */
#define PIN_LED_ACTIVITY    GPIO_NUM_38
#define PIN_LED_STATUS      GPIO_NUM_48

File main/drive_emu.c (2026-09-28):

/*
 * Virtual Shugart drive. See drive_emu.h.
 *
 * Every interrupt recomputes all outputs from the live select level under
 * a spinlock. Whichever of a STEP, MOTOR, WGATE and deselect interrupt runs
 * last sees the real select level, so no output can stay active after
 * deselection. STEP moves the head on the trailing (rising) edge of the
 * active-low pulse.
 */
#include "freertos/FreeRTOS.h"
#include "driver/gpio.h"
#include "hal/gpio_ll.h"
#include "esp_attr.h"
#include "esp_timer.h"

#include "soc/io_mux_reg.h"

#include "board_pins.h"
#include "disk_image.h"
#include "drive_config.h"
#include "drive_emu.h"
#include "flux_stream.h"
#include "step_sound.h"

#define EVENT_QUEUE_LEN 256

static portMUX_TYPE drive_lock = portMUX_INITIALIZER_UNLOCKED;
static bool armed;
static volatile int current_track = 0;  /* assumed at track 0 at start-up */
static QueueHandle_t event_queue;
static volatile uint32_t select_edges;
gpio_num_t emu_select_line = EMU_DS1;
static volatile uint32_t ignored_steps;
static bool disk_present;
static int64_t media_change_until_us;
static volatile bool writable;          /* WPROT released: see drive_set_writable() */
static volatile int64_t last_index_us;  /* start of the last INDEX pulse */
static drive_write_start_t write_start; /* last WGATE assertion */
static bool wrote_while_selected;       /* WGATE since our drive was selected */

int IRAM_ATTR drive_cylinder(void)
{
    return current_track;
}

/* Call with drive_lock held. IRAM-safe. */
static void IRAM_ATTR update_outputs_locked(drive_status_t *st)
{
    bool active = armed && emulator_is_selected();
    bool changing = media_change_until_us && esp_timer_get_time() < media_change_until_us;
    bool disk = disk_present && !changing;

    st->armed = armed;
    st->selected = emulator_is_selected();
    st->motor = gpio_ll_get_level(&GPIO, PIN_FDD_MOTOR) == 0;
    st->wgate = gpio_ll_get_level(&GPIO, PIN_FDD_WGATE) == 0;
    st->track0 = active && current_track == 0;
    /* Write protect: asserted for a read-only disk; released for a disk
     * that may be written. During a disk change the opposite, so TOS always
     * sees the transition it uses to notice the change. */
    st->wprot = active && (changing ? writable : !writable);
    st->index = active && disk && st->motor;
    st->rdata = active && disk && st->motor && !st->wgate;
    st->cyl = current_track;
    st->side = gpio_ll_get_level(&GPIO, PIN_FDD_SIDE) ? 0 : 1;

    /* GPIO HIGH = ULN2003A pulls the Shugart line LOW = asserted. */
    gpio_ll_set_level(&GPIO, PIN_FDD_TRK0, st->track0);
    gpio_ll_set_level(&GPIO, PIN_FDD_WPROT, st->wprot);
    flux_gate(st->rdata, st->index);

    if (!active) {
        step_sound_stop_isr();      /* no sound from us for another drive */
    }
}

static void IRAM_ATTR drive_isr(void *arg)
{
    drive_event_t ev = { .type = (uint8_t)(uintptr_t)arg };
    bool log;

    portENTER_CRITICAL_ISR(&drive_lock);
    if (ev.type == DRV_EV_STEP && armed && emulator_is_selected()) {
        if (gpio_ll_get_level(&GPIO, PIN_FDD_DIR) == 0) {
            if (current_track < DRIVE_MAX_TRACK) {
                current_track++;        /* DIR LOW: inward */
            }
        } else if (current_track > 0) {
            current_track--;            /* DIR HIGH: towards track 0 */
        }
        step_sound_step_isr();          /* also at a limit: the motor still clicks */
        log = true;
    } else {
        log = ev.type == DRV_EV_SELECT ? armed : armed && emulator_is_selected();
        if (ev.type == DRV_EV_STEP) {
            ignored_steps++;
            log = false;
        }
    }
    update_outputs_locked(&ev.st);
    if (ev.type == DRV_EV_WGATE && ev.st.wgate && armed && ev.st.selected) {
        /* A write starts: where on which track, and was it allowed. */
        write_start = (drive_write_start_t) {
            .time_us = esp_timer_get_time(),
            .index_us = last_index_us,
            .cyl = current_track,
            .side = ev.st.side,
            .writable = writable && !ev.st.wprot,
            .gen = disk_media_gen,
            .seq = write_start.seq + 1,
        };
        wrote_while_selected = true;
    }
    if (ev.type == DRV_EV_SELECT && !ev.st.selected) {
        wrote_while_selected = false;
    }
    portEXIT_CRITICAL_ISR(&drive_lock);

    if (ev.type == DRV_EV_SELECT) {
        select_edges++;
    }
    if (!log) {
        return;
    }

    ev.time_us = esp_timer_get_time();
    BaseType_t woken = pdFALSE;
    xQueueSendFromISR(event_queue, &ev, &woken);   /* full: drop log only */
    if (woken) {
        portYIELD_FROM_ISR();
    }
}

/* Our own INDEX output (read back from the pad): the rotation reference. */
static void IRAM_ATTR index_isr(void *arg)
{
    last_index_us = esp_timer_get_time();
}

void drive_init(void)
{
    event_queue = xQueueCreate(EVENT_QUEUE_LEN, sizeof(drive_event_t));
    assert(event_queue);

    const gpio_config_t cfg = {
        .pin_bit_mask = (1ULL << PIN_FDD_DS0) | (1ULL << PIN_FDD_DS1) |
                        (1ULL << PIN_FDD_MOTOR) | (1ULL << PIN_FDD_DIR) |
                        (1ULL << PIN_FDD_STEP) | (1ULL << PIN_FDD_WDATA) |
                        (1ULL << PIN_FDD_WGATE) | (1ULL << PIN_FDD_SIDE),
        .mode = GPIO_MODE_INPUT,
        .pull_up_en = GPIO_PULLUP_DISABLE,      /* driven by the SN74LVC245A */
        .pull_down_en = GPIO_PULLDOWN_DISABLE,
        .intr_type = GPIO_INTR_DISABLE,
    };
    ESP_ERROR_CHECK(gpio_config(&cfg));

    const struct {                  /* select line: from the settings */
        gpio_num_t pin;
        gpio_int_type_t edge;
        drive_event_type_t type;
    } irqs[] = {
        { EMU_SELECT_LINE, GPIO_INTR_ANYEDGE, DRV_EV_SELECT },
        { PIN_FDD_MOTOR,   GPIO_INTR_ANYEDGE, DRV_EV_MOTOR },
        { PIN_FDD_WGATE,   GPIO_INTR_ANYEDGE, DRV_EV_WGATE },
        { PIN_FDD_SIDE,    GPIO_INTR_ANYEDGE, DRV_EV_SIDE },
        { PIN_FDD_STEP,    GPIO_INTR_POSEDGE, DRV_EV_STEP },   /* trailing edge */
    };

    ESP_ERROR_CHECK(gpio_install_isr_service(ESP_INTR_FLAG_IRAM));
    for (size_t i = 0; i < sizeof(irqs) / sizeof(irqs[0]); i++) {
        ESP_ERROR_CHECK(gpio_set_intr_type(irqs[i].pin, irqs[i].edge));
        ESP_ERROR_CHECK(gpio_isr_handler_add(irqs[i].pin, drive_isr,
                                             (void *)(uintptr_t)irqs[i].type));
    }

    /* INDEX is an output (RMT, GPIO HIGH = pulse); its pad is read back
     * so the rising edge marks the start of every revolution. */
    PIN_INPUT_ENABLE(GPIO_PIN_MUX_REG[PIN_FDD_INDEX]);
    ESP_ERROR_CHECK(gpio_set_intr_type(PIN_FDD_INDEX, GPIO_INTR_POSEDGE));
    ESP_ERROR_CHECK(gpio_isr_handler_add(PIN_FDD_INDEX, index_isr, NULL));
}

void drive_arm(drive_status_t *status)
{
    portENTER_CRITICAL(&drive_lock);
    armed = true;
    update_outputs_locked(status);
    portEXIT_CRITICAL(&drive_lock);
}
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

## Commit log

2026-09-24 ESP32-S3 WiFi floppy emulator: first read-only Atari ST emulation
    Bring-up firmware for the RadioFloppy PCB (ESP32-S3 N16R8, SN74LVC245A
    inputs, ULN2003A outputs on a 34-pin Shugart connector).
    - Hardware tests: push buttons + buzzer, Shugart output->input loopback.
    - Shugart outputs released from the bootloader onwards; 50 ms start-up
    guard on the drive-select line before the drive is armed.
    - Read-only drive emulation (EMU_SELECT_LINE, default DS1 = drive B:):
    virtual head (STEP on trailing edge), TRACK0, WPROT, INDEX, RDATA.
    - MFM tracks in FlashFloppy .ST layout, pre-encoded in PSRAM and
    verified; flux stream via RMT + DMA (0.8 us pulses, 10 MHz), INDEX via
    a second RMT channel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
    [partitions.csv]
2026-09-24 Load floppy images from the external SPI flash (image store v1)
    - ext_flash: S25FL128L (JEDEC 01 60 18, 16 MiB) on SPI2/FSPI pins,
    single SPI at 20 MHz via the ESP-IDF generic chip driver; WP#/IO2 and
    IO3/RESET# held high. All calls use our own chip handle, never NULL.
    - image_store: RadioFloppy image store format v1 (docs/IMAGE_STORE.md):
    catalog copies A/B with generation, CRC-32 and commit word, 60
    records, images from 0x010000, 4 KiB aligned. Images are written as
    building -> erase own sectors -> program -> byte-for-byte verify ->
    valid. Unknown flash content is never overwritten.
    - disk_image: raw image from the external flash into PSRAM with CRC
    check, then the unchanged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
    [disk_image.c, ext_flash.c, floppy_app.c]
2026-09-24 Remove embedded images: floppy images come only from the external flash
    The firmware no longer contains any floppy image, provisioning or
    fallback path. The image named DISK_EXTERNAL_IMAGE is loaded from the
    external SPI flash image store; if it is missing or corrupt the drive
    stays disabled. Firmware size 617 KB -> 246 KB.
    Tested on the Atari STf: Crystal Castles loads from the external flash.
    [disk_image.c, floppy_app.c]
2026-09-24 Add STEP click sound and MOTOR status LED
    - step_sound: a short click (STEP_SOUND_PULSE_MS, 3 ms) on the active
    buzzer (GPIO20) for every STEP pulse our drive processes, from the
    existing drive ISR. The ISR only switches the buzzer on and starts a
    one-shot esp_timer; a click is never stretched (min. off time, at most
    one queued click) and stops at once on deselection.
    - status_led: on-board WS2812-type LED (GPIO48 on this board) red-orange
    while MOTOR is active (LOW), own RMT channel, polled by a low-priority
    task. led_test.c blinks GPIO38 blue / GPIO48 red to locate the LED.
    - flux_stream: remove the RMT sync manager once RDATA and INDEX run; its
    group-wide tx_sim_en kept the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
    [board_pins.h, drive_emu.c, floppy_app.c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]
2026-09-24 Status LED: dimmed orange, only while our drive is selected and MOTOR is on
2026-09-24 Slot store, HTTP API, web interface, disk buttons and fast disk switching
    Storage (external SPI flash, docs/FLASH_LAYOUT.md)
    - 20 fixed 800 KiB image slots from 0x010000, 64 KiB metadata area with
    two slot catalog copies (generation, CRC-32, commit word), 320 KiB tail
    reserved. Central map in main/flash_layout.h.
    - slot_store: prepare (building) -> erase only the needed sectors ->
    write -> read back + CRC -> valid; delete; free-slot search.
    - Legacy v1 catalog read-only; Crystal Castles migrated to slot 1 without
    moving data.
    HTTP API v1 (docs/API.md) and WiFi
    - WiFi station, lwIP and httpd on core 1, credentials from menuconfig
    (sdkconfig, git-ignored), RAM storage: no flash writ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
    [buttons.c, disk_image.c]
2026-09-24 Support 80-84 cylinders and 9-11 sectors per track
    - MFM tracks for 9, 10 or 11 sectors of 512 bytes, laid out as
    FlashFloppy does for .ST (GAP3 84 / 30 / 3, interleave 2 for 11
    sectors). 9-sector tracks are bit-for-bit unchanged.
    - 11-sector tracks do not fit 100000 bitcells: they are 102848 cells long
    and the flux encoder spreads every track over exactly 200 ms with
    fractional bitcell timing, so INDEX stays locked (2 us cells for 9 and
    10 sectors, 1.945 us for 11).
    - Head positions up to 83, track buffers for 84 cylinders; tracks beyond
    the image are unformatted.
    - .ST validation: geometry from the file size, confirmed by a valid BPB
    (sectors/sides must agree, the file system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
    [disk_image.c, floppy_app.c, flux_stream.c]
2026-09-25 Add OLED display: disk title, track view, WiFi signal and boot screen
    - SSD1306 128x32 over I2C (GPIO47/21): boot screen "RadioFloppy v1.0.0"
    for 2 s (version from PROJECT_VER), then the active disk title over
    two lines with 11-row glyphs.
    - While drive B: is selected with the motor on, line 2 shows
    "Track NN Side S"; back to the title when the motor goes off.
    - WiFi signal bars at the right of line 2 (RSSI, 3 dB hysteresis).
    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
2026-09-25 Block-based image library, settings page, WiFi setup mode, drive select
    Image library (replaces the 20 fixed 800 KiB slots):
    - Flash divided into logical blocks, block size chosen from the detected
    capacity (64 KiB on 16 MiB, 255 data blocks, uint8_t block numbers).
    - Images are ordered block lists (max 24), up to 1.5 MiB, RAW storage
    (storage_format reserved for compression). Catalog v2 ("RFIL") with two
    copies in block 0, full validation on load; old slot format recognised
    but never read (POST /storage/format). No migration.
    - Save/replace/delete/reorder with verify-before-valid; replace reuses the
    old blocks first and works on a nearly full flash.
    - API: /images, /images/{id}, /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
    [buttons.c, disk_image.c]
2026-09-25 Remember the last disk, buzzer setting, drive A: first in settings
    - The active library image is stored in the settings 5 s after the last
    disk change (one flash write when stepping through disks, none when
    unchanged) and loaded again at start-up; PSRAM images are not
    remembered. Falls back to Crystal Castles, then the first image.
    - Setting "buzzer" (step and button clicks), effective at once.
    - Settings page: drive A: listed before B:; new Sound section.
    - Settings record v3 (buzzer_off, last_image_id in former padding;
    v1/v2 still read); settings access serialised by a mutex.
    [disk_image.c, floppy_app.c, step_sound.c]
2026-09-27 Connected-computer setting, settings page layout, MAC address
    - Setting "machine" (ATARI default, AMIGA and DOS reserved) in the
    settings record (v4; older records read as ATARI), via the API and the
    settings page. Machine profiles in main/machine.c for later interfaces
    and formats. An unsupported profile starts without floppy emulation
    (no drive interrupts, no flux stream, outputs released); web, API,
    image library and WiFi setup keep working, disk switches give
    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
2026-09-27 Write support for Atari .ST images, new blank disks, per-image write setting
    - Per-image write setting (READ_ONLY default, READ_WRITE) in bit 7 of the
    record's format byte (existing records read as READ_ONLY); format ids
    reserved for MSA/STX/IPF/HFE/ADF/IMG, only ST may be writable.
    PUT /images/{id} {"access"}; switch per image on the web page.
    - New disk: POST /api/v1/images {"name"} creates an empty, formatted
    720 KiB .ST (80x2x9, TOS layout) as READ_WRITE, for the Atari profile
    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
2026-09-27 Optional compression of new images; save written sectors after motor off
    - Setting "compression" (Settings -> Storage, default off; settings
    record v5): new read-only images are deflated with the ROM miniz,
    inflated again and CRC-checked before storing (else stored RAW).
    Stored images are left as they are. Loading inflates transparently.
    Storage format DEFLATE in the catalog record; setting a compressed
    image to READ_WRITE unpacks it copy-on-write.
    - Compression runs in a short-lived task with its own stack (the ROM
    compressor overflowed the HTTP server stack); the check inflates with
    a 32 KiB window instead of a second full image buffer.
    - The sectors of the active disk are ke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
    [disk_image.c, disk_write.c]
2026-09-27 HFE validator, catalog v3, downloads, icon buttons; fix flash deadlock
    - HFE phase 1: main/hfe.c checks HFEv1/v3 files (header, track table,
    v3 opcodes, track buffer fit) and decodes tracks; HFEv2 is refused.
    Uploads are checked but refused until HFE playback exists. Host tests.
    - Catalog version 3: compressed images may be up to 3 MiB logical size;
    version 2 catalogs are still read and upgraded on the next update.
    - Compression on: always compress, also writable disks (whole-image
    copy-on-write save).
    - GET /api/v1/images/{id}/data downloads the uncompressed image.
    - Web UI: icon buttons, drag handle for the order, Insert button,
    "Write protected", HFE files accepted with the devi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
    [disk_image.c, disk_write.c, ext_flash.c]
2026-09-27 Add KiCad design of the board, revision 2 (hardware/v1.1)
    Schematic, PCB, project, symbol and footprints, schematic PDF, board
    image and production files (BOM, placement, netlist, gerber zip).
    KiCad backups, lock/autosave files, caches and per-user settings are
    ignored.
    [Floppy emulator.kicad_pcb, Floppy emulator.kicad_sch, bom.csv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]
2026-09-27 HFE uploads as a stream: never the whole file in PSRAM
    - hfe.c: streaming reader (header, track table, one cylinder at a time
    in a 64 KiB region) decoding straight into the packed track buffer
    format of the player; checking a file runs the same packing counting
    only, so a file that passes also fits when played. Track table first
    and tracks in ascending order required (HFE_BAD_LAYOUT otherwise).
    - img_codec: streaming deflate (ROM tdefl in a worker task on core 1)
    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
2026-09-27 WIP: HFE player (phase 2), untested
    Native timing mode in flux_stream (HFE data encoder with timing
    segments, INDEX encoder on the exact revolution-boundary ticks,
    restart of both channels on an ST <-> HFE disk change), HFE disks
    loaded from the flash straight into the track buffer (disk_image,
    disk_switch, start-up), activation after an HFE upload.
    Builds without warnings; not flashed or tested yet. HFE_PLAYBACK in
    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
2026-09-28 HFE player: enable playback, first device test results
    HFE_PLAYBACK 1 on wip/hfe-player. Flashed and tested: ST regression
    passes (api_test 68/0, ui_test 49/0); Pang and Pink Panther HFE images
    load on the Atari, P-47 (custom-format tracks) hangs after its intro.
    The handoff notes record the results and the Windows laptop setup.
    ui_test.py: the Chrome executable can be set with $CHROME.
2026-09-28 Change disks while the drive is selected
    Many games keep drive B: selected all the time, and with the Atari off
    the select line floats (board revision 1 lacks the DS0/DS1 pull-ups), so
    disk changes often ended in DRIVE_BUSY.
    After 0.3 s a disk is now also changed while the drive stays selected,
    like ejecting a disk from a real drive: the 0.7 s disk change signal
    keeps INDEX/RDATA off, so no half sector of the new disk is read. Refused
    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
2026-09-28 Web UI: messages time out, upload refusals stop the progress bar
    - Success messages disappear after 15 s; errors and warnings stay.
    - An upload refused by the device stops the progress bar.
    - "Load temporarily" is disabled for HFE files (always stored).
    - DRIVE_BUSY texts say the Atari is writing to the drive.
2026-09-28 HFEv3 from flux dumps: smooth the timing, accept the repeated INDEX
    HFEv3 files made from flux dumps (SCP via HxC) carry thousands of
    BITRATE opcodes per track (the dumping drive's speed jitter) and repeat
    the INDEX opcode just before the track end. Such tracks are now smoothed
    into equal zones that keep the exact revolution time, an INDEX in the
    last 1/64 of a track is ignored, and surplus weak areas are joined.
    HFE_MAX_SEGMENTS 16 -> 32; the opcode counter is 32 bits.
    Klax (Greaseweazle dump, HxC HFEv3) now loads and runs on the Atari.
    Host test for a flux-style track; run.sh takes extra files from
    HFE_TEST_FILES. Handoff notes updated with this round's results.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
2026-09-28 OLED: end the track view when our drive is deselected
    The MOTOR line alone can stay on: the FDC only switches it off after
    index pulses, which a deselected drive does not give, and on board
    revision 1 it floats while the computer is off. The track view now also
    ends 1 s after our drive was deselected, like the status LED.
2026-09-29 Board revision 2: pin map, shared SPI bus, LEDs on J4
    Revision 2 (hardware/v1.1) moves the buzzer to GPIO46, LED_STATUS to
    GPIO20, LED_ACTIVITY to GPIO48 and adds an SD card module on the NOR
    flash's SPI bus (SD_CS GPIO38). Revision 1 is no longer supported.
    - board_pins.h: rev 2 map, checked against all U1 pads of the PCB.
    - SD_CS and NOR_CS are driven HIGH in the bootloader hook and in
    app_main, so a card in J5 never answers flash traffic.
    - leds.c replaces the WS2812 status LED: ACTIVITY while drive B: is
    selected with MOTOR on; STATUS shows WiFi (off connected, 1 Hz joining,
    on after 60 s without connection, 4 Hz in setup mode).
    - Removed the rev 1 bring-up tests (led_test, button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
    [board.c, board_pins.h, button_test.c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]
2026-10-21 Front panel LEDs: setting for one or two LEDs on J4
    - New setting "leds" (1 or 2, default 1): web Settings ("Front panel
    LEDs"), GET/PUT /api/v1/settings; settings record version 6 (the byte
    was padding in 5; older records read as 1). Takes effect at once.
    - J4 pin 3 (GPIO20) now always shows disk activity (our drive selected
    and MOTOR on).
    - WiFi status (blinking while connecting, on when no connection can be
    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
2026-10-23 Web UI: SD card block (browse, upload, folders, delete)
    - New "SD card" section on the home page: breadcrumb from the root
    directory, folders first then files with sizes (sorted), click a
    folder to open it.
    - "Upload here..." for one or more .ST/.HFE files into the current
    folder, with progress; an existing file is only replaced after asking.
    - "New folder" (asks for a name) and a delete button per file and
    folder; a folder with contents needs a second confirmation and is then
    removed with everything in it.
    - Answers for a folder that was left meanwhile are ignored, and the list
    is not refreshed while the page is busy (uploads).
    - No card: "No SD card in RadioFloppy"; firmware wi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
2026-10-23 Insert .ST images from the SD card; last disk remembered as SD path
    - disk_switch_sd(): reads the file from the card (sd_card_load), checks
    it as .ST and makes it the active disk, read-only (source DISK_SRC_SD,
    disk_info_t.sd_path). HFE from the card comes later.
    - Settings record version 8: last_sd (the SD path of the disk active at
    power-off, or ""); last_image_id and last_sd exclude each other. The
    remember task stores either. At start-up the SD card is mounted first
    and the last disk is read from it; a missing card or file falls back
    to the library.
    - Deleting or replacing the active file (or a folder holding it) flags
    the current disk as changed, as for library images.
    - A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
2026-10-24 Writing to the SD card through a journal in the flash
    The Atari can write to an .ST file on the SD card unless the file has the
    FAT read-only attribute.
    - Save (motor off 2 s): the changed 64 KiB blocks go into the flash copy
    of the disk, which is read back and committed as pending (copy header
    v3: pending, base_crc, sync word); then the same blocks are written
    into the file in place, read back and checked; then the copy is marked
    synced. A pending copy is written to the card at the next start-up.
    - When the file was replaced or deleted meanwhile, the changes are kept
    as "<name> (changes).st" next to it (write.note says so).
    - Write protection follows the file (read-only attribute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
2026-10-24 Save written sectors also when drive B: is not selected for 3 s
    On the rev 2 board the MOTOR input reads as on all the time while the ST
    is idle, so "motor off for 2 s" never started a save; it only came after
    the 60 s fallback. A save now also starts 3 s after the drive was last
    selected.
    SAVE_TEST_PAUSE_MS (default 0) pauses a save between the flash journal
    and the SD card, for power-cut tests. Tested that way: an ESP reset in
    the pause, the changes were written from the flash to the card at
    start-up, and the image checked on a PC.
    Docs: API.md (when a save starts), handoff (test results, MOTOR note for
    the next board; the old wip/board-rev2 heading).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
2026-10-24 HFE INDEX on the exact tick; flux monitor to measure the drive outputs
    Flux monitor (debug, off by default; GET/PUT /api/v1/debug/flux): MCPWM
    capture of the INDEX pin (period and width per track) and an RMT
    recording of the RDATA pin compared with the track in memory, while the
    computer reads. Measurements across a step, side or select change are
    skipped (drive_head_events).
    It showed the HFE INDEX off by up to 1.3 ms (late_pulses 1123 with
    P-47): the INDEX channel filled its 48-symbol memory with 10 us steps and
    needed a refill every 0.24 ms; a late refill replayed old symbols and
    delayed every later pulse. Now the data encoder publishes when the
    current revolution ends (last boundary + t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
